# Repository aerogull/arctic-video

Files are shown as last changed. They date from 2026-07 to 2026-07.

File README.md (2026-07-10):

# Arctic-Video
#### An FPGA card designed around video, audio, and PCIe.
Built on a Xilinx Artix-7 75T FPGA chip, with jtag programming, video and audio ports on the card, and DDR3L RAM.

- XC7A75T-2FGG676C
- 256Mb spi flash
- 1GB DDR3L RAM
- 2 6G-SDI ports
- 1 2-lane DisplayPort
- PCIe gen 2 x4 interface
- JTAG programming
- 6 status LEDs

This hardware is untested, use the designs at your own risk!

schematic
pcb
3d model
render

An interactive bom, which includes jlc estimated prices, can be found in the ibom.html file in root. There is a full blend file and a file for the pcb bracket in the cad folder.

JLCPCB estimates:

PCB production costs $165.41

PCBA costs $392.47

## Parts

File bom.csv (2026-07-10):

Designator | Footprint | Quantity | Value | LCSC Part #
C1 | 0402 | 1 | 100u
C10, C11, C13, C16, C20, C23, C26, C28, C29, C47, C48, C49, C50, C51, C52, C53, C54, C55, C56, C57, C58, C59, C60, C61, C62, C63, C64, C65, C66, C76, C77, C78, C79, C8, C80, C81, C82, C83, C84, C85, C86, C87 | 0402 | 42 | 0.47u
C100, C101, C102, C103, C108, C126, C127, C128, C129, C132, C133, C158, C88, C89, C90, C91, C93, C95, C96, C98, C99 | 0402 | 21 | 0.1u
C104, C123, C124, C125, C138, C139, C14, C15, C37, C38, C39, C40, C41, C42, C43, C44, C45, C46, C7, C70, C71, C72, C73, C74, C75, C9, C92, C94, C97 | 0402 | 29 | 4.7u
C105, C107, C109, C110, C111, C122, C142, C143, C144, C145, C150, C152, C3, C4, C5, C6, L1, L2, L3 | 0402 | 19 | 10u
C106 | 0402 | 1 | 1000p
C112 | 0402 | 1 | 2.2u
C113, C114, C115, C116, C117, C118, C119, C120, C134, C135, C146, C147, C148, C149, C151, C153, C154, C155, C156, C157 | 0402 | 20 | 100n
C12, C19, C27, C32, C33, C34, C35, C36, C67, C68, C69 | 0603 | 11 | 47u
C121, C130, C24, C25, C30, C31 | 0402 | 6 | 22u
C131, C136, C137 | 0402 | 3 | 1u
C140, C141 | 0402 | 2 | 470n
C17, C18 | 0402 | 2 | 10n
C2 | 0402 | 1 | 47u
C21, C22 | 0402 | 2 | 3.9n
D1, D2, D3, D4, D5, D6, D7 | 0402 | 7 | LED
IC1, IC2 | QFN40P400X600X100-41N-D | 2 | GS12142
J1 | CONN_47272-0024_MOL | 1 | 472720024
J2, J3 | SAMTEC_BNC7T-J-P-XX-ST-EM1D | 2 | Conn_Coaxial
J4 | PinSocket_2x05_P2.54mm_Vertical | 1 | Conn_ARM_JTAG_SWD_10
J5 | BUS_PCIexpress_x4 | 1 | Bus_PCI_Express_x4
R1, R13, R17, R2, R42, R44, R49, R50, R51, R52, R55, R56, R57, R58, R59, R60 | 0402 | 16 | 100k
R10 | 0402 | 1 | 800
R11, R14, R15, R16, R18, R20, R23, R24, R25, R26, R35, R36, R37, R38, R39, R40, R41, R45, R46, R61, R62, R64, R66, R68, R69, R7, R70, R71, R8 | 0402 | 29 | 10k
R12, R19, R22 | 0402 | 3 | 1M
R21 | 0402 | 1 | 5M
R27, R28, R29, R30, R31, R32, R33, R47 | 0402 | 8 | 1k
R3 | 0402 | 1 | 180
R34 | 0402 | 1 | 240
R4 | 0402 | 1 | 2.2k
R43 | 0402 | 1 | 24.9k
R48 | 0402 | 1 | 22
R5, R6 | 0402 | 2 | 6.8k
R53, R54 | 0402 | 2 | 2
R63 | 0402 | 1 | 100
R65, R67 | 0402 | 2 | 12.1k
R9 | 0402 | 1 | 26.1k
SW1 | SW_DIP_SPSTx08_Slide_9.78x22.5mm_W7.62mm_P2.54mm | 1 | SW_DIP_x08
U1 | Xilinx_FGG676 | 1 | XC7A75T-FGG676
U10 | DRC0010J | 1 | TPS51200DRCR
U11 | DQC0010A | 1 | TPS62175DQCR
U12, U6 | SOT23_NEX | 2 | PESD5V0L2BT
U13, U4 | SOT_AMS1117-2.5_AMS | 2 | AMS1117-ADJ
U2, U3 | IC8_MP2307_MNP | 2 | MP2307DN-LF-Z
U5 | SOT223_AMS1117-1.8_AMS | 1 | AMS1117-1.8
U7 | RTQ0056B | 1 | HD3SS215IRTQT
U8 | SON_EW7-0SIT_MRN | 1 | MT25QL256ABA1EW7-0SIT
U9 | FBGA96_8X14_MRN | 1 | MT41K256M16TW-107:P
XTAL1 | CHIP_ASE-24_ABR | 1 | ASE-25.000MHZ-LC-T
XTAL2 | SG-210STF_EPS | 1 | SX3M100.000B20F30TNN

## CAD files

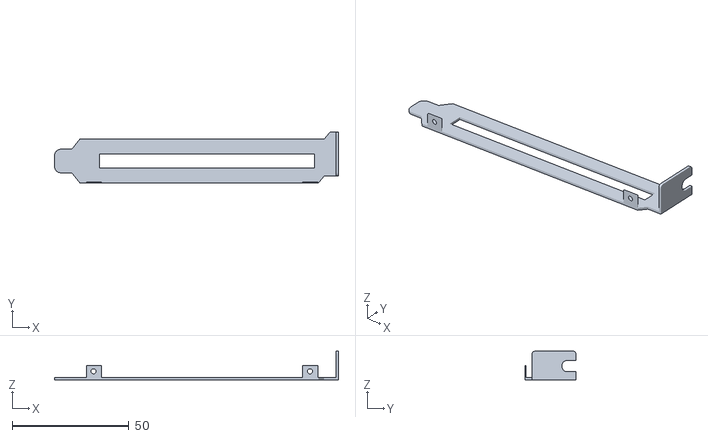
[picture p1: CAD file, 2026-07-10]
cad/arctic-video-bracket.stl
121.4 x 21.8 x 12.3

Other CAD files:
cad/arctic-video.blend

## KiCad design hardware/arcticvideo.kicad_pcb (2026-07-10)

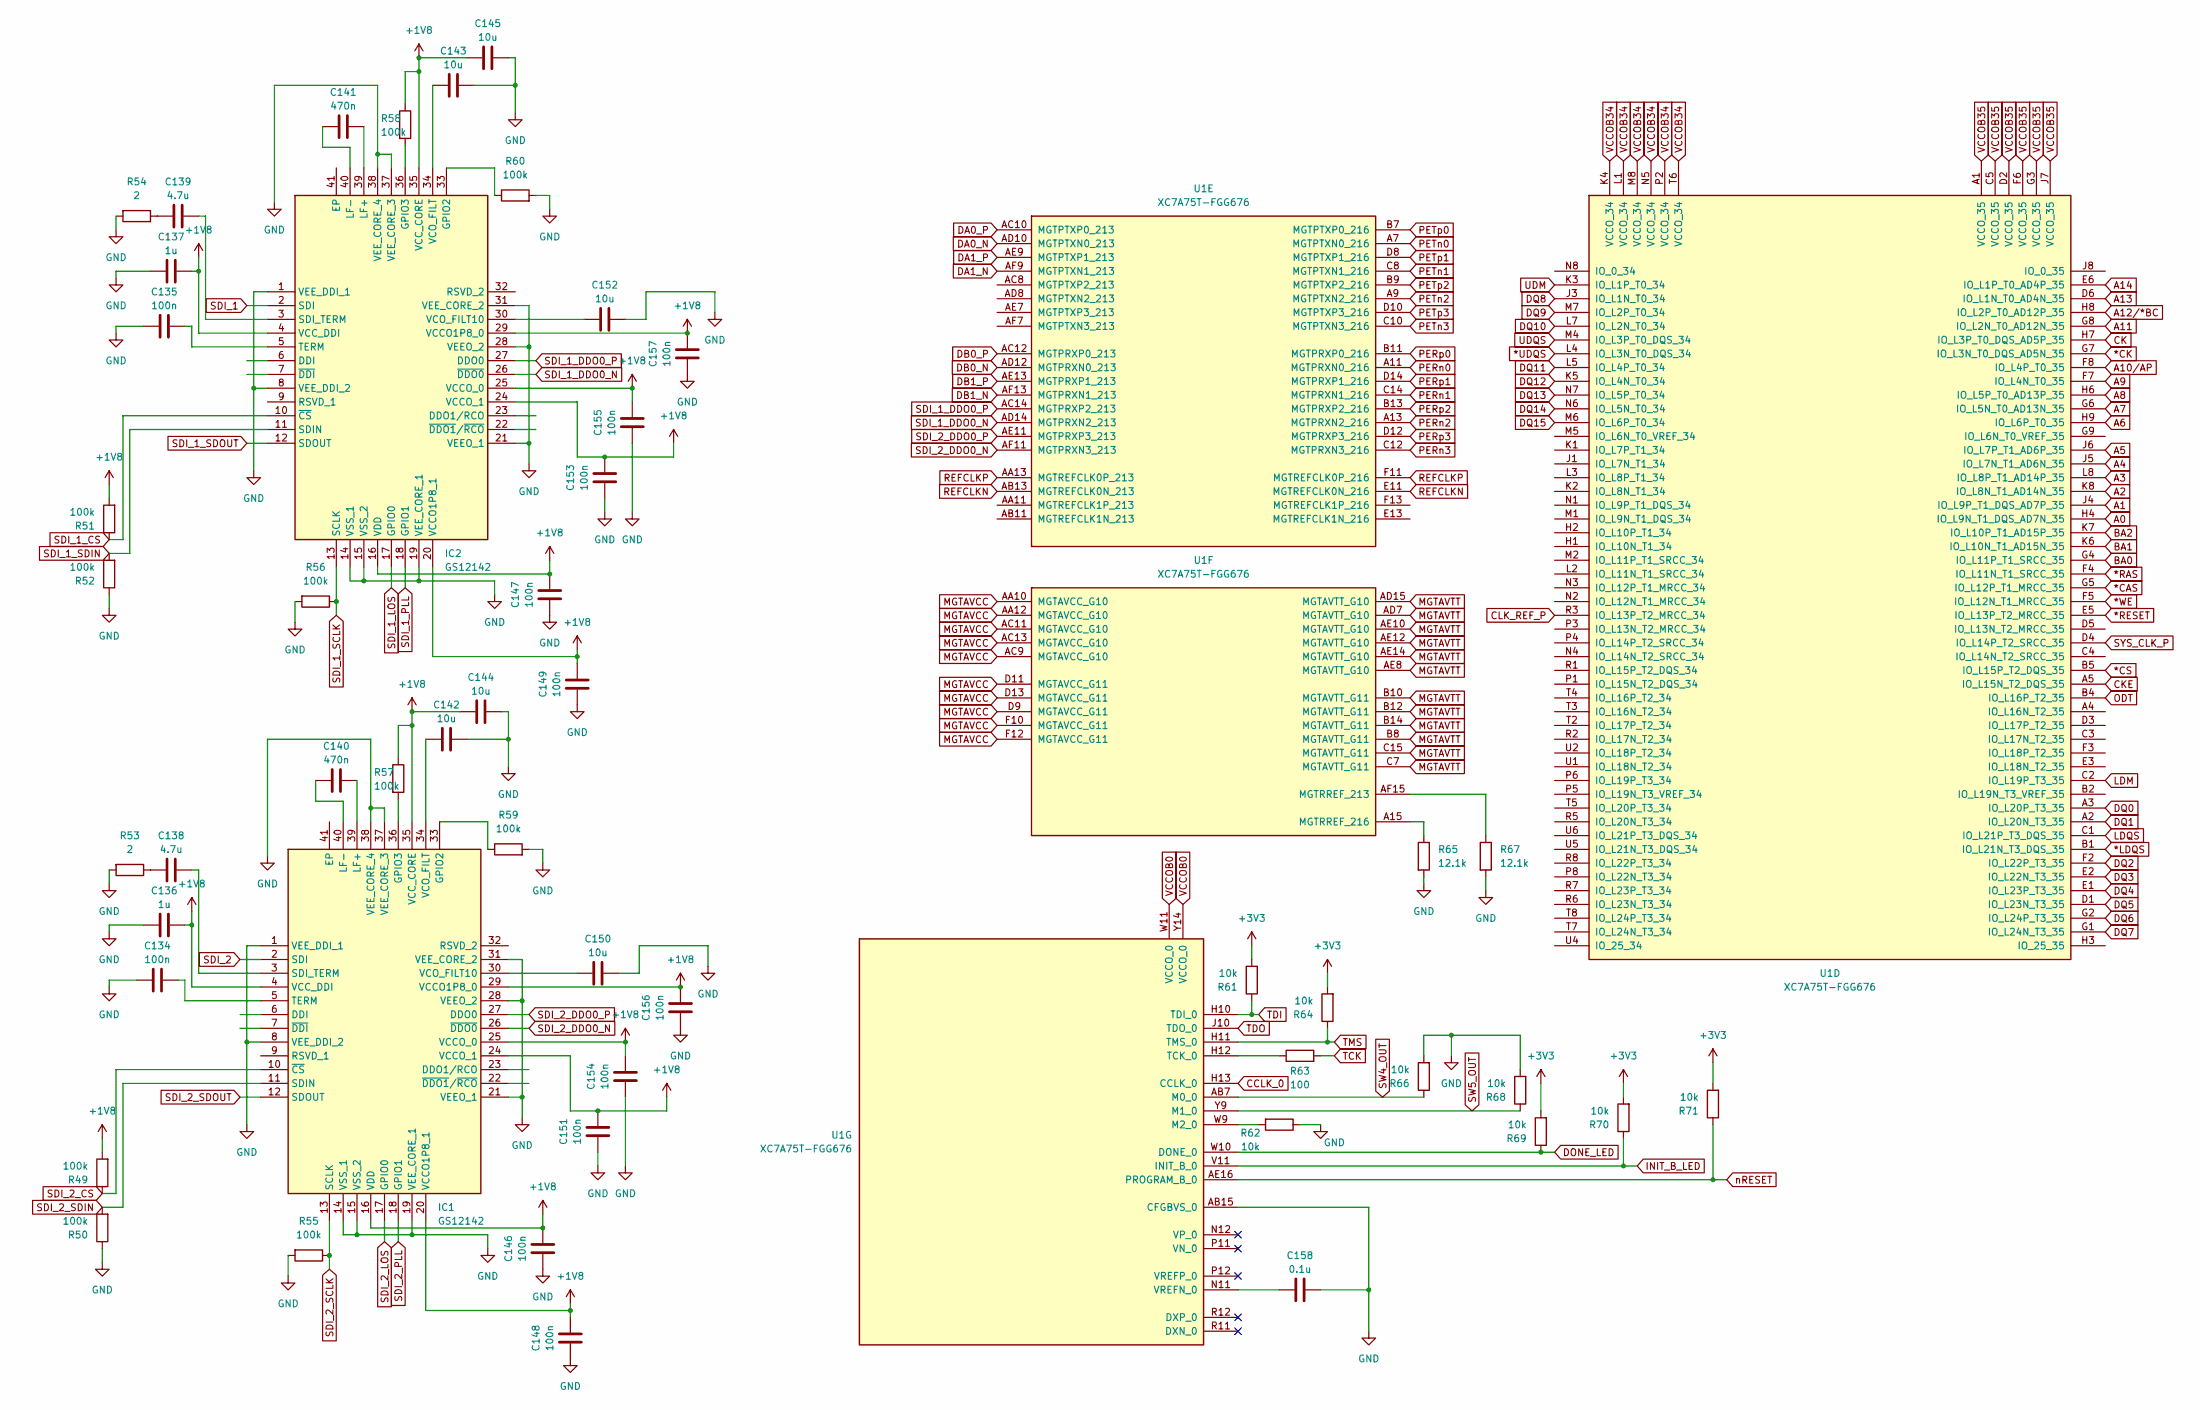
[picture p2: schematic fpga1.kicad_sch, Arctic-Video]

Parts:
C134, C135, C146, C147, C148, C149, C151, C153, C154, C155, C156, C157: 100n; C_0402_1005Metric
C136, C137: 1u; C_0402_1005Metric
C138, C139: 4.7u; C_0402_1005Metric
C140, C141: 470n; C_0402_1005Metric
C142, C143, C144, C145, C150, C152: 10u; C_0402_1005Metric
C158: 0.1u; C_0402_1005Metric
IC1, IC2: GS12142; QFN40P400X600X100-41N-D; Manufacturer_Part_Number GS12142
R49, R50, R51, R52, R55, R56, R57, R58, R59, R60: 100k; R_0402_1005Metric
R53, R54: 2; R_0402_1005Metric
R61, R62, R64, R66, R68, R69, R70, R71: 10k; R_0402_1005Metric
R63: 100; R_0402_1005Metric
R65, R67: 12.1k; R_0402_1005Metric
U1: XC7A75T-FGG676; Xilinx_FGG676

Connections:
*CAS: U1.G5 (IO_L12P_T1_MRCC_35); also elsewhere on the board
*CK: U1.G7 (IO_L3N_T0_DQS_AD5N_35); also elsewhere on the board
*CS: U1.B5 (IO_L15P_T2_DQS_35); also elsewhere on the board
*LDQS: U1.B1 (IO_L21N_T3_DQS_35); also elsewhere on the board
*RAS: U1.F4 (IO_L11N_T1_SRCC_35); also elsewhere on the board
*RESET: U1.E5 (IO_L13P_T2_MRCC_35); also elsewhere on the board
*UDQS: U1.L4 (IO_L3N_T0_DQS_34); also elsewhere on the board
*WE: U1.F5 (IO_L12N_T1_MRCC_35); also elsewhere on the board
A0: U1.H4 (IO_L9N_T1_DQS_AD7N_35); also elsewhere on the board
A1: U1.J4 (IO_L9P_T1_DQS_AD7P_35); also elsewhere on the board
A2: U1.K8 (IO_L8N_T1_AD14N_35); also elsewhere on the board
A3: U1.L8 (IO_L8P_T1_AD14P_35); also elsewhere on the board
A4: U1.J5 (IO_L7N_T1_AD6N_35); also elsewhere on the board
A5: U1.J6 (IO_L7P_T1_AD6P_35); also elsewhere on the board
A6: U1.H9 (IO_L6P_T0_35); also elsewhere on the board
A7: U1.G6 (IO_L5N_T0_AD13N_35); also elsewhere on the board
A8: U1.H6 (IO_L5P_T0_AD13P_35); also elsewhere on the board
A9: U1.F7 (IO_L4N_T0_35); also elsewhere on the board
A10/AP: U1.F8 (IO_L4P_T0_35); also elsewhere on the board
A11: U1.G8 (IO_L2N_T0_AD12N_35); also elsewhere on the board
A12/*BC: U1.H8 (IO_L2P_T0_AD12P_35); also elsewhere on the board
A13: U1.D6 (IO_L1N_T0_AD4N_35); also elsewhere on the board
A14: U1.E6 (IO_L1P_T0_AD4P_35); also elsewhere on the board
BA0: U1.G4 (IO_L11P_T1_SRCC_35); also elsewhere on the board
BA1: U1.K6 (IO_L10N_T1_AD15N_35); also elsewhere on the board
BA2: U1.K7 (IO_L10P_T1_AD15P_35); also elsewhere on the board
CCLK_0: U1.H13 (CCLK_0); also elsewhere on the board
CK: U1.H7 (IO_L3P_T0_DQS_AD5P_35); also elsewhere on the board
CKE: U1.A5 (IO_L15N_T2_DQS_35); also elsewhere on the board
CLK_REF_P: U1.D4 (IO_L14P_T2_SRCC_35), U1.R3 (IO_L13P_T2_MRCC_34); also elsewhere on the board
DA0_N: U1.AD10 (MGTPTXN0_213); also elsewhere on the board
DA0_P: U1.AC10 (MGTPTXP0_213); also elsewhere on the board
DA1_N: U1.AF9 (MGTPTXN1_213); also elsewhere on the board
DA1_P: U1.AE9 (MGTPTXP1_213); also elsewhere on the board
DB0_N: U1.AD12 (MGTPRXN0_213); also elsewhere on the board
DB0_P: U1.AC12 (MGTPRXP0_213); also elsewhere on the board
DB1_N: U1.AF13 (MGTPRXN1_213); also elsewhere on the board
DB1_P: U1.AE13 (MGTPRXP1_213); also elsewhere on the board
DONE_LED: R69.1, U1.W10 (DONE_0); also elsewhere on the board
DQ0: U1.A3 (IO_L20P_T3_35); also elsewhere on the board
DQ1: U1.A2 (IO_L20N_T3_35); also elsewhere on the board
DQ2: U1.F2 (IO_L22P_T3_35); also elsewhere on the board
DQ3: U1.E2 (IO_L22N_T3_35); also elsewhere on the board
DQ4: U1.E1 (IO_L23P_T3_35); also elsewhere on the board
DQ5: U1.D1 (IO_L23N_T3_35); also elsewhere on the board
DQ6: U1.G2 (IO_L24P_T3_35); also elsewhere on the board
DQ7: U1.G1 (IO_L24N_T3_35); also elsewhere on the board
DQ8: U1.J3 (IO_L1N_T0_34); also elsewhere on the board
DQ9: U1.M7 (IO_L2P_T0_34); also elsewhere on the board
DQ10: U1.L7 (IO_L2N_T0_34); also elsewhere on the board
DQ11: U1.L5 (IO_L4P_T0_34); also elsewhere on the board
DQ12: U1.K5 (IO_L4N_T0_34); also elsewhere on the board
DQ13: U1.N7 (IO_L5P_T0_34); also elsewhere on the board
DQ14: U1.N6 (IO_L5N_T0_34); also elsewhere on the board
DQ15: U1.M6 (IO_L6P_T0_34); also elsewhere on the board
GND: C134.1, C135.1, C136.1, C137.1, C142.2, C143.2, C144.2, C145.2, C146.1, C147.1, C148.1, C149.1, C150.2, C151.1, C152.2, C153.1, C154.1, C155.1, C156.1, C157.1, C158.2, IC1.1 (VEE_DDI_1), IC1.8 (VEE_DDI_2), IC1.14 (VSS_1), IC1.15 (VSS_2), IC1.19 (VEE_CORE_1), IC1.21 (VEEO_1), IC1.28 (VEEO_2), IC1.31 (VEE_CORE_2), IC1.37 (VEE_CORE_3), IC1.38 (VEE_CORE_4), IC2.1 (VEE_DDI_1), IC2.8 (VEE_DDI_2), IC2.14 (VSS_1), IC2.15 (VSS_2), IC2.19 (VEE_CORE_1), IC2.21 (VEEO_1), IC2.28 (VEEO_2), IC2.31 (VEE_CORE_2), IC2.37 (VEE_CORE_3), IC2.38 (VEE_CORE_4), R50.1, R52.1, R53.2, R54.2, R55.2, R56.2, R59.2, R60.2, R62.1, R65.2, R66.2, R67.2, R68.2, U1.AB15 (CFGBVS_0); also elsewhere on the board
INIT_B_LED: R70.1, U1.V11 (INIT_B_0); also elsewhere on the board
LDM: U1.C2 (IO_L19P_T3_35); also elsewhere on the board
LDQS: U1.C1 (IO_L21P_T3_DQS_35); also elsewhere on the board
MGTAVCC: U1.AA10 (MGTAVCC_G10), U1.AA12 (MGTAVCC_G10), U1.AC9 (MGTAVCC_G10), U1.AC11 (MGTAVCC_G10), U1.AC13 (MGTAVCC_G10), U1.D9 (MGTAVCC_G11), U1.D11 (MGTAVCC_G11), U1.D13 (MGTAVCC_G11), U1.F10 (MGTAVCC_G11), U1.F12 (MGTAVCC_G11); also elsewhere on the board
MGTAVTT: U1.AD7 (MGTAVTT_G10), U1.AD15 (MGTAVTT_G10), U1.AE8 (MGTAVTT_G10), U1.AE10 (MGTAVTT_G10), U1.AE12 (MGTAVTT_G10), U1.AE14 (MGTAVTT_G10), U1.B8 (MGTAVTT_G11), U1.B10 (MGTAVTT_G11), U1.B12 (MGTAVTT_G11), U1.B14 (MGTAVTT_G11), U1.C7 (MGTAVTT_G11), U1.C15 (MGTAVTT_G11); also elsewhere on the board
unnamed: C138.1, R53.1
unnamed: C139.1, R54.1
unnamed: IC1.33 (GPIO2), R59.1
unnamed: IC1.36 (GPIO3), R57.2
unnamed: C140.2, IC1.39 (LF+)
unnamed: C140.1, IC1.40 (LF-)
unnamed: C138.2, IC1.3 (SDI_TERM)
unnamed: C134.2, IC1.5 (TERM)
unnamed: C150.1, IC1.30 (VCO_FILT10)
unnamed: C142.1, IC1.34 (VCO_FILT)
unnamed: IC2.33 (GPIO2), R60.1
unnamed: IC2.36 (GPIO3), R58.2
unnamed: C141.2, IC2.39 (LF+)
unnamed: C141.1, IC2.40 (LF-)
unnamed: C139.2, IC2.3 (SDI_TERM)
unnamed: C135.2, IC2.5 (TERM)
unnamed: C152.1, IC2.30 (VCO_FILT10)
unnamed: C143.1, IC2.34 (VCO_FILT)
unnamed: R67.1, U1.AF15 (MGTRREF_213)
unnamed: R65.1, U1.A15 (MGTRREF_216)
unnamed: R62.2, U1.W9 (M2_0)
unnamed: R63.1, U1.H12 (TCK_0)
unnamed: C158.1, U1.N11 (VREFN_0)
ODT: U1.B4 (IO_L16P_T2_35); also elsewhere on the board
PERn0: U1.A11 (MGTPRXN0_216); also elsewhere on the board
PERn1: U1.C14 (MGTPRXN1_216); also elsewhere on the board
PERn2: U1.A13 (MGTPRXN2_216); also elsewhere on the board
PERn3: U1.C12 (MGTPRXN3_216); also elsewhere on the board
PERp0: U1.B11 (MGTPRXP0_216); also elsewhere on the board
PERp1: U1.D14 (MGTPRXP1_216); also elsewhere on the board
PERp2: U1.B13 (MGTPRXP2_216); also elsewhere on the board
PERp3: U1.D12 (MGTPRXP3_216); also elsewhere on the board
PETn0: U1.A7 (MGTPTXN0_216); also elsewhere on the board
PETn1: U1.C8 (MGTPTXN1_216); also elsewhere on the board
PETn2: U1.A9 (MGTPTXN2_216); also elsewhere on the board
PETn3: U1.C10 (MGTPTXN3_216); also elsewhere on the board
PETp0: U1.B7 (MGTPTXP0_216); also elsewhere on the board
PETp1: U1.D8 (MGTPTXP1_216); also elsewhere on the board
PETp2: U1.B9 (MGTPTXP2_216); also elsewhere on the board
PETp3: U1.D10 (MGTPTXP3_216); also elsewhere on the board
REFCLKN: U1.AB13 (MGTREFCLK0N_213), U1.E11 (MGTREFCLK0N_216); also elsewhere on the board
REFCLKP: U1.AA13 (MGTREFCLK0P_213), U1.F11 (MGTREFCLK0P_216); also elsewhere on the board
SDI_1: IC2.2 (SDI); also elsewhere on the board
SDI_1_CS: IC2.10 (~CS), R51.1; also elsewhere on the board
SDI_1_DDO0_N: IC2.26 (~DDO0), U1.AD14 (MGTPRXN2_213)
SDI_1_DDO0_P: IC2.27 (DDO0), U1.AC14 (MGTPRXP2_213)
SDI_1_LOS: IC2.17 (GPIO0); also elsewhere on the board
SDI_1_PLL: IC2.18 (GPIO1); also elsewhere on the board
SDI_1_SCLK: IC2.13 (SCLK), R56.1; also elsewhere on the board
SDI_1_SDIN: IC2.11 (SDIN), R52.2; also elsewhere on the board
SDI_1_SDOUT: IC2.12 (SDOUT); also elsewhere on the board
SDI_2: IC1.2 (SDI); also elsewhere on the board
SDI_2_CS: IC1.10 (~CS), R49.1; also elsewhere on the board
SDI_2_DDO0_N: IC1.26 (~DDO0), U1.AF11 (MGTPRXN3_213)
SDI_2_DDO0_P: IC1.27 (DDO0), U1.AE11 (MGTPRXP3_213)
SDI_2_LOS: IC1.17 (GPIO0); also elsewhere on the board
SDI_2_PLL: IC1.18 (GPIO1); also elsewhere on the board
SDI_2_SCLK: IC1.13 (SCLK), R55.1; also elsewhere on the board
SDI_2_SDIN: IC1.11 (SDIN), R50.2; also elsewhere on the board
SDI_2_SDOUT: IC1.12 (SDOUT); also elsewhere on the board
SW4_OUT: R66.1, U1.AB7 (M0_0); also elsewhere on the board
SW5_OUT: R68.1, U1.Y9 (M1_0); also elsewhere on the board
TCK: R63.2; also elsewhere on the board
TDI: R61.1, U1.H10 (TDI_0); also elsewhere on the board
TDO: U1.J10 (TDO_0); also elsewhere on the board
TMS: R64.1, U1.H11 (TMS_0); also elsewhere on the board
UDM: U1.K3 (IO_L1P_T0_34); also elsewhere on the board
UDQS: U1.M4 (IO_L3P_T0_DQS_34); also elsewhere on the board
VCCAUX: C136.2, C137.2, C144.1, C145.1, C146.2, C147.2, C148.2, C149.2, C151.2, C153.2, C154.2, C155.2, C156.2, C157.2, IC1.4 (VCC_DDI), IC1.16 (VDD), IC1.20 (VCCO1P8_1), IC1.24 (VCCO_1), IC1.25 (VCCO_0), IC1.29 (VCCO1P8_0), IC1.35 (VCC_CORE), IC2.4 (VCC_DDI), IC2.16 (VDD), IC2.20 (VCCO1P8_1), IC2.24 (VCCO_1), IC2.25 (VCCO_0), IC2.29 (VCCO1P8_0), IC2.35 (VCC_CORE), R49.2, R51.2, R57.1, R58.1; also elsewhere on the board
VCCOB0: R61.2, R64.2, R69.2, R70.2, R71.2, U1.W11 (VCCO_0), U1.Y14 (VCCO_0); also elsewhere on the board
VCCOB33: U1.A1 (VCCO_35), U1.C5 (VCCO_35), U1.D2 (VCCO_35), U1.F6 (VCCO_35), U1.G3 (VCCO_35), U1.J7 (VCCO_35), U1.K4 (VCCO_34), U1.L1 (VCCO_34), U1.M8 (VCCO_34), U1.N5 (VCCO_34), U1.P2 (VCCO_34), U1.T6 (VCCO_34); also elsewhere on the board
nRESET: R71.1, U1.AE16 (PROGRAM_B_0); also elsewhere on the board

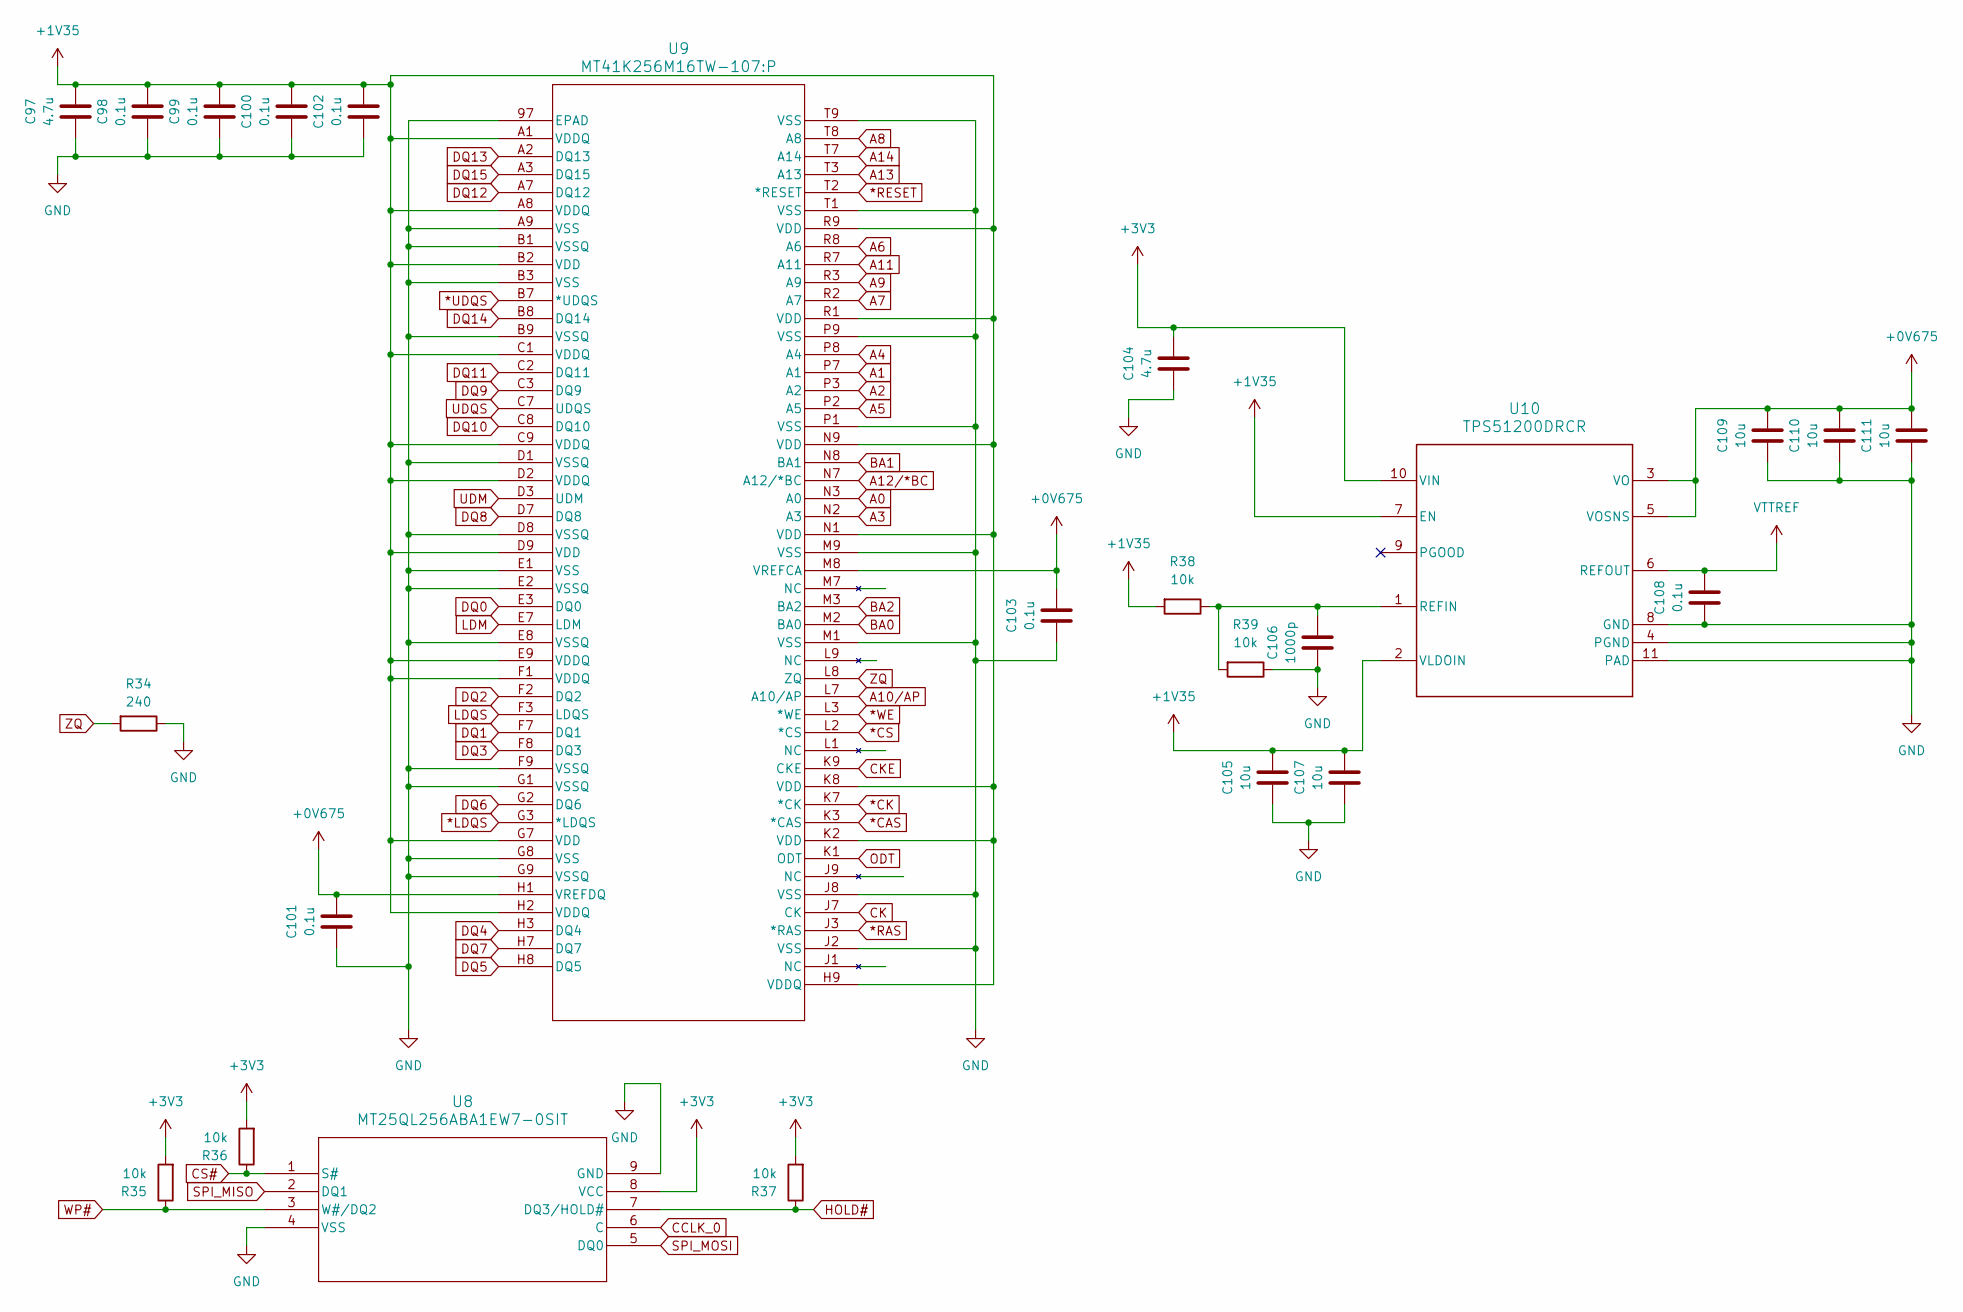
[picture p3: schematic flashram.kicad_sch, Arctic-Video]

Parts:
C97, C104: 4.7u; C_0402_1005Metric
C98, C99, C100, C101, C102, C103, C108: 0.1u; C_0402_1005Metric
C105, C107, C109, C110, C111: 10u; C_0402_1005Metric
C106: 1000p; C_0402_1005Metric
R34: 240; R_0402_1005Metric
R35, R36, R37, R38, R39: 10k; R_0402_1005Metric
U8: MT25QL256ABA1EW7-0SIT; SON_EW7-0SIT_MRN
U9: MT41K256M16TW-107:P; FBGA96_8X14_MRN
U10: TPS51200DRCR; DRC0010J

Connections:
*CAS: U9.K3 (*CAS); also elsewhere on the board
*CK: U9.K7 (*CK); also elsewhere on the board
*CS: U9.L2 (*CS); also elsewhere on the board
*LDQS: U9.G3 (*LDQS); also elsewhere on the board
*RAS: U9.J3 (*RAS); also elsewhere on the board
*RESET: U9.T2 (*RESET); also elsewhere on the board
*UDQS: U9.B7 (*UDQS); also elsewhere on the board
*WE: U9.L3 (*WE); also elsewhere on the board
+0V675: C101.2, C103.2, C109.2, C110.2, C111.2, U9.H1 (VREFDQ), U9.M8 (VREFCA), U10.3 (VO), U10.5 (VOSNS)
A0: U9.N3 (A0); also elsewhere on the board
A1: U9.P7 (A1); also elsewhere on the board
A2: U9.P3 (A2); also elsewhere on the board
A3: U9.N2 (A3); also elsewhere on the board
A4: U9.P8 (A4); also elsewhere on the board
A5: U9.P2 (A5); also elsewhere on the board
A6: U9.R8 (A6); also elsewhere on the board
A7: U9.R2 (A7); also elsewhere on the board
A8: U9.T8 (A8); also elsewhere on the board
A9: U9.R3 (A9); also elsewhere on the board
A10/AP: U9.L7 (A10/AP); also elsewhere on the board
A11: U9.R7 (A11); also elsewhere on the board
A12/*BC: U9.N7 (A12/*BC); also elsewhere on the board
A13: U9.T3 (A13); also elsewhere on the board
A14: U9.T7 (A14); also elsewhere on the board
BA0: U9.M2 (BA0); also elsewhere on the board
BA1: U9.N8 (BA1); also elsewhere on the board
BA2: U9.M3 (BA2); also elsewhere on the board
CCLK_0: U8.6 (C); also elsewhere on the board
CK: U9.J7 (CK); also elsewhere on the board
CKE: U9.K9 (CKE); also elsewhere on the board
CS#: R36.1, U8.1 (S#); also elsewhere on the board
DQ0: U9.E3 (DQ0); also elsewhere on the board
DQ1: U9.F7 (DQ1); also elsewhere on the board
DQ2: U9.F2 (DQ2); also elsewhere on the board
DQ3: U9.F8 (DQ3); also elsewhere on the board
DQ4: U9.H3 (DQ4); also elsewhere on the board
DQ5: U9.H8 (DQ5); also elsewhere on the board
DQ6: U9.G2 (DQ6); also elsewhere on the board
DQ7: U9.H7 (DQ7); also elsewhere on the board
DQ8: U9.D7 (DQ8); also elsewhere on the board
DQ9: U9.C3 (DQ9); also elsewhere on the board
DQ10: U9.C8 (DQ10); also elsewhere on the board
DQ11: U9.C2 (DQ11); also elsewhere on the board
DQ12: U9.A7 (DQ12); also elsewhere on the board
DQ13: U9.A2 (DQ13); also elsewhere on the board
DQ14: U9.B8 (DQ14); also elsewhere on the board
DQ15: U9.A3 (DQ15); also elsewhere on the board
GND: C97.1, C98.1, C99.1, C100.1, C101.1, C102.1, C103.1, C104.1, C105.1, C106.1, C107.1, C108.1, C109.1, C110.1, C111.1, R34.1, R39.1, U8.4 (VSS), U8.9 (GND), U9.97 (EPAD), U9.A9 (VSS), U9.B1 (VSSQ), U9.B3 (VSS), U9.B9 (VSSQ), U9.D1 (VSSQ), U9.D8 (VSSQ), U9.E1 (VSS), U9.E2 (VSSQ), U9.E8 (VSSQ), U9.F9 (VSSQ), U9.G1 (VSSQ), U9.G8 (VSS), U9.G9 (VSSQ), U9.J2 (VSS), U9.J8 (VSS), U9.M1 (VSS), U9.M9 (VSS), U9.P1 (VSS), U9.P9 (VSS), U9.T1 (VSS), U9.T9 (VSS), U10.4 (PGND), U10.8 (GND), U10.11 (PAD); also elsewhere on the board
HOLD#: R37.1, U8.7 (DQ3/HOLD#); also elsewhere on the board
LDM: U9.E7 (LDM); also elsewhere on the board
LDQS: U9.F3 (LDQS); also elsewhere on the board
unnamed: C106.2, R38.1, R39.2, U10.1 (REFIN)
ODT: U9.K1 (ODT); also elsewhere on the board
SPI_MISO: U8.2 (DQ1); also elsewhere on the board
SPI_MOSI: U8.5 (DQ0); also elsewhere on the board
UDM: U9.D3 (UDM); also elsewhere on the board
UDQS: U9.C7 (UDQS); also elsewhere on the board
VCCOB0: C104.2, R35.2, R36.2, R37.2, U8.8 (VCC), U10.10 (VIN); also elsewhere on the board
VCCOB33: C97.2, C98.2, C99.2, C100.2, C102.2, C105.2, C107.2, R38.2, U9.A1 (VDDQ), U9.A8 (VDDQ), U9.B2 (VDD), U9.C1 (VDDQ), U9.C9 (VDDQ), U9.D2 (VDDQ), U9.D9 (VDD), U9.E9 (VDDQ), U9.F1 (VDDQ), U9.G7 (VDD), U9.H2 (VDDQ), U9.H9 (VDDQ), U9.K2 (VDD), U9.K8 (VDD), U9.N1 (VDD), U9.N9 (VDD), U9.R1 (VDD), U9.R9 (VDD), U10.2 (VLDOIN), U10.7 (EN); also elsewhere on the board
VTTREF: C108.2, U10.6 (REFOUT)
WP#: R35.1, U8.3 (W#/DQ2); also elsewhere on the board
ZQ: R34.2, U9.L8 (ZQ)

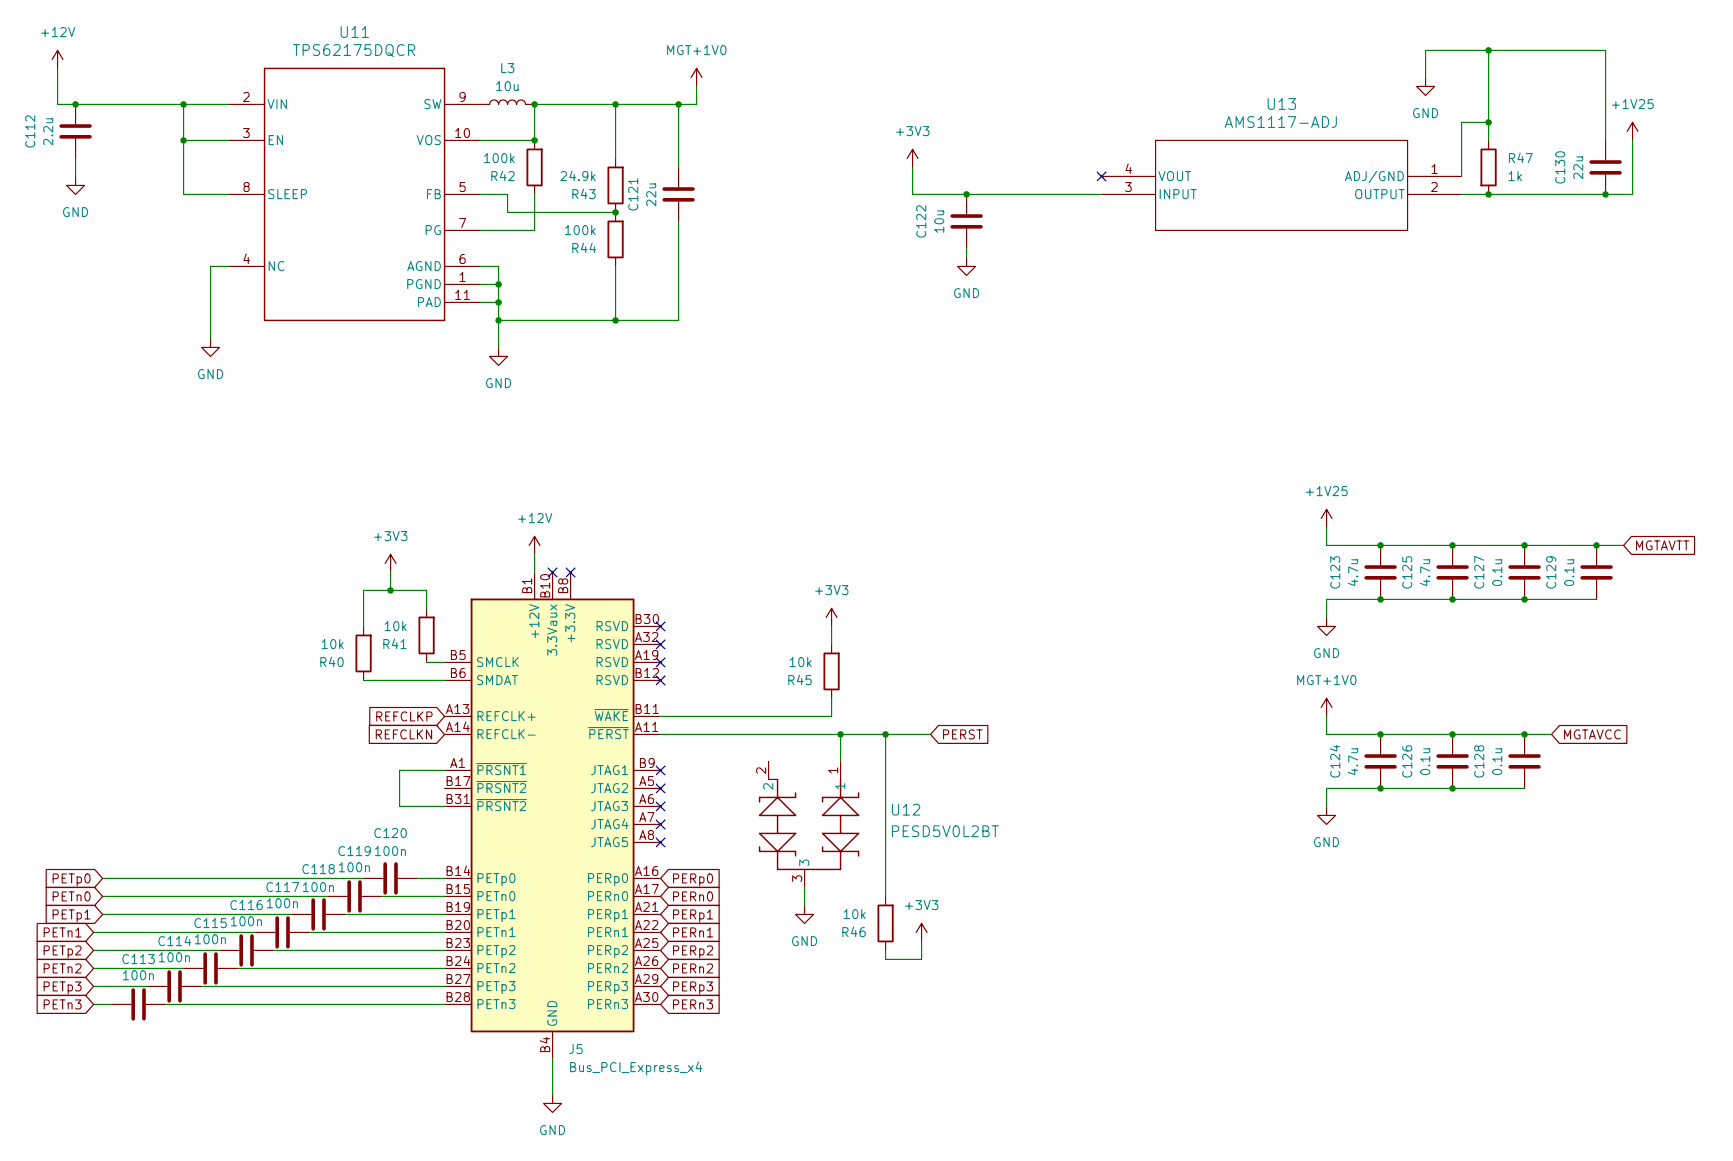
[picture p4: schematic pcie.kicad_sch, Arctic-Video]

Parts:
C112: 2.2u; C_0402_1005Metric
C113, C114, C115, C116, C117, C118, C119, C120: 100n; C_0402_1005Metric
C121, C130: 22u; C_0402_1005Metric
C122: 10u; C_0402_1005Metric
C123, C124, C125: 4.7u; C_0402_1005Metric
C126, C127, C128, C129: 0.1u; C_0402_1005Metric
J5: Bus_PCI_Express_x4; BUS_PCIexpress_x4
L3: 10u; L_0402_1005Metric
R40, R41, R45, R46: 10k; R_0402_1005Metric
R42, R44: 100k; R_0402_1005Metric
R43: 24.9k; R_0402_1005Metric
R47: 1k; R_0402_1005Metric
U11: TPS62175DQCR; DQC0010A
U12: PESD5V0L2BT; SOT23_NEX
U13: AMS1117-ADJ; SOT_AMS1117-2.5_AMS

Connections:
+12V: C112.2, J5.A2 (+12V), J5.A3 (+12V), J5.B1 (+12V), J5.B2 (+12V), J5.B3 (+12V), U11.2 (VIN), U11.3 (EN), U11.8 (SLEEP); also elsewhere on the board
GND: C112.1, C121.1, C122.1, C123.1, C124.1, C125.1, C126.1, C127.1, C128.1, C129.1, C130.2, J5.A4 (GND), J5.A12 (GND), J5.A15 (GND), J5.A18 (GND), J5.A20 (GND), J5.A23 (GND), J5.A24 (GND), J5.A27 (GND), J5.A28 (GND), J5.A31 (GND), J5.B4 (GND), J5.B7 (GND), J5.B13 (GND), J5.B16 (GND), J5.B18 (GND), J5.B21 (GND), J5.B22 (GND), J5.B25 (GND), J5.B26 (GND), J5.B29 (GND), J5.B32 (GND), R44.1, R47.1, U11.1 (PGND), U11.4 (NC), U11.6 (AGND), U11.11 (PAD), U12.3, U13.1 (ADJ/GND); also elsewhere on the board
MGTAVCC: C121.2, C124.2, C126.2, C128.2, L3.2, R42.2, R43.2, U11.10 (VOS); also elsewhere on the board
MGTAVTT: C123.2, C125.2, C127.2, C129.2, C130.1, R47.2, U13.2 (OUTPUT); also elsewhere on the board
unnamed: C119.2, J5.B15 (PETn0)
unnamed: C117.2, J5.B20 (PETn1)
unnamed: C115.2, J5.B24 (PETn2)
unnamed: C113.2, J5.B28 (PETn3)
unnamed: C120.2, J5.B14 (PETp0)
unnamed: C118.2, J5.B19 (PETp1)
unnamed: C116.2, J5.B23 (PETp2)
unnamed: C114.2, J5.B27 (PETp3)
unnamed: J5.B5 (SMCLK), R41.1
unnamed: J5.B6 (SMDAT), R40.1
unnamed: J5.A1 (~PRSNT1), J5.B31 (~PRSNT2)
unnamed: J5.B11 (~WAKE), R45.1
unnamed: R43.1, R44.2, U11.5 (FB)
unnamed: R42.1, U11.7 (PG)
unnamed: L3.1, U11.9 (SW)
PERST: J5.A11 (~PERST), R46.2, U12.1; also elsewhere on the board
PERn0: J5.A17 (PERn0); also elsewhere on the board
PERn1: J5.A22 (PERn1); also elsewhere on the board
PERn2: J5.A26 (PERn2); also elsewhere on the board
PERn3: J5.A30 (PERn3); also elsewhere on the board
PERp0: J5.A16 (PERp0); also elsewhere on the board
PERp1: J5.A21 (PERp1); also elsewhere on the board
PERp2: J5.A25 (PERp2); also elsewhere on the board
PERp3: J5.A29 (PERp3); also elsewhere on the board
PETn0: C119.1; also elsewhere on the board
PETn1: C117.1; also elsewhere on the board
PETn2: C115.1; also elsewhere on the board
PETn3: C113.1; also elsewhere on the board
PETp0: C120.1; also elsewhere on the board
PETp1: C118.1; also elsewhere on the board
PETp2: C116.1; also elsewhere on the board
PETp3: C114.1; also elsewhere on the board
REFCLKN: J5.A14 (REFCLK-); also elsewhere on the board
REFCLKP: J5.A13 (REFCLK+); also elsewhere on the board
VCCOB0: C122.2, R40.2, R41.2, R45.2, R46.1, U13.3 (INPUT); also elsewhere on the board

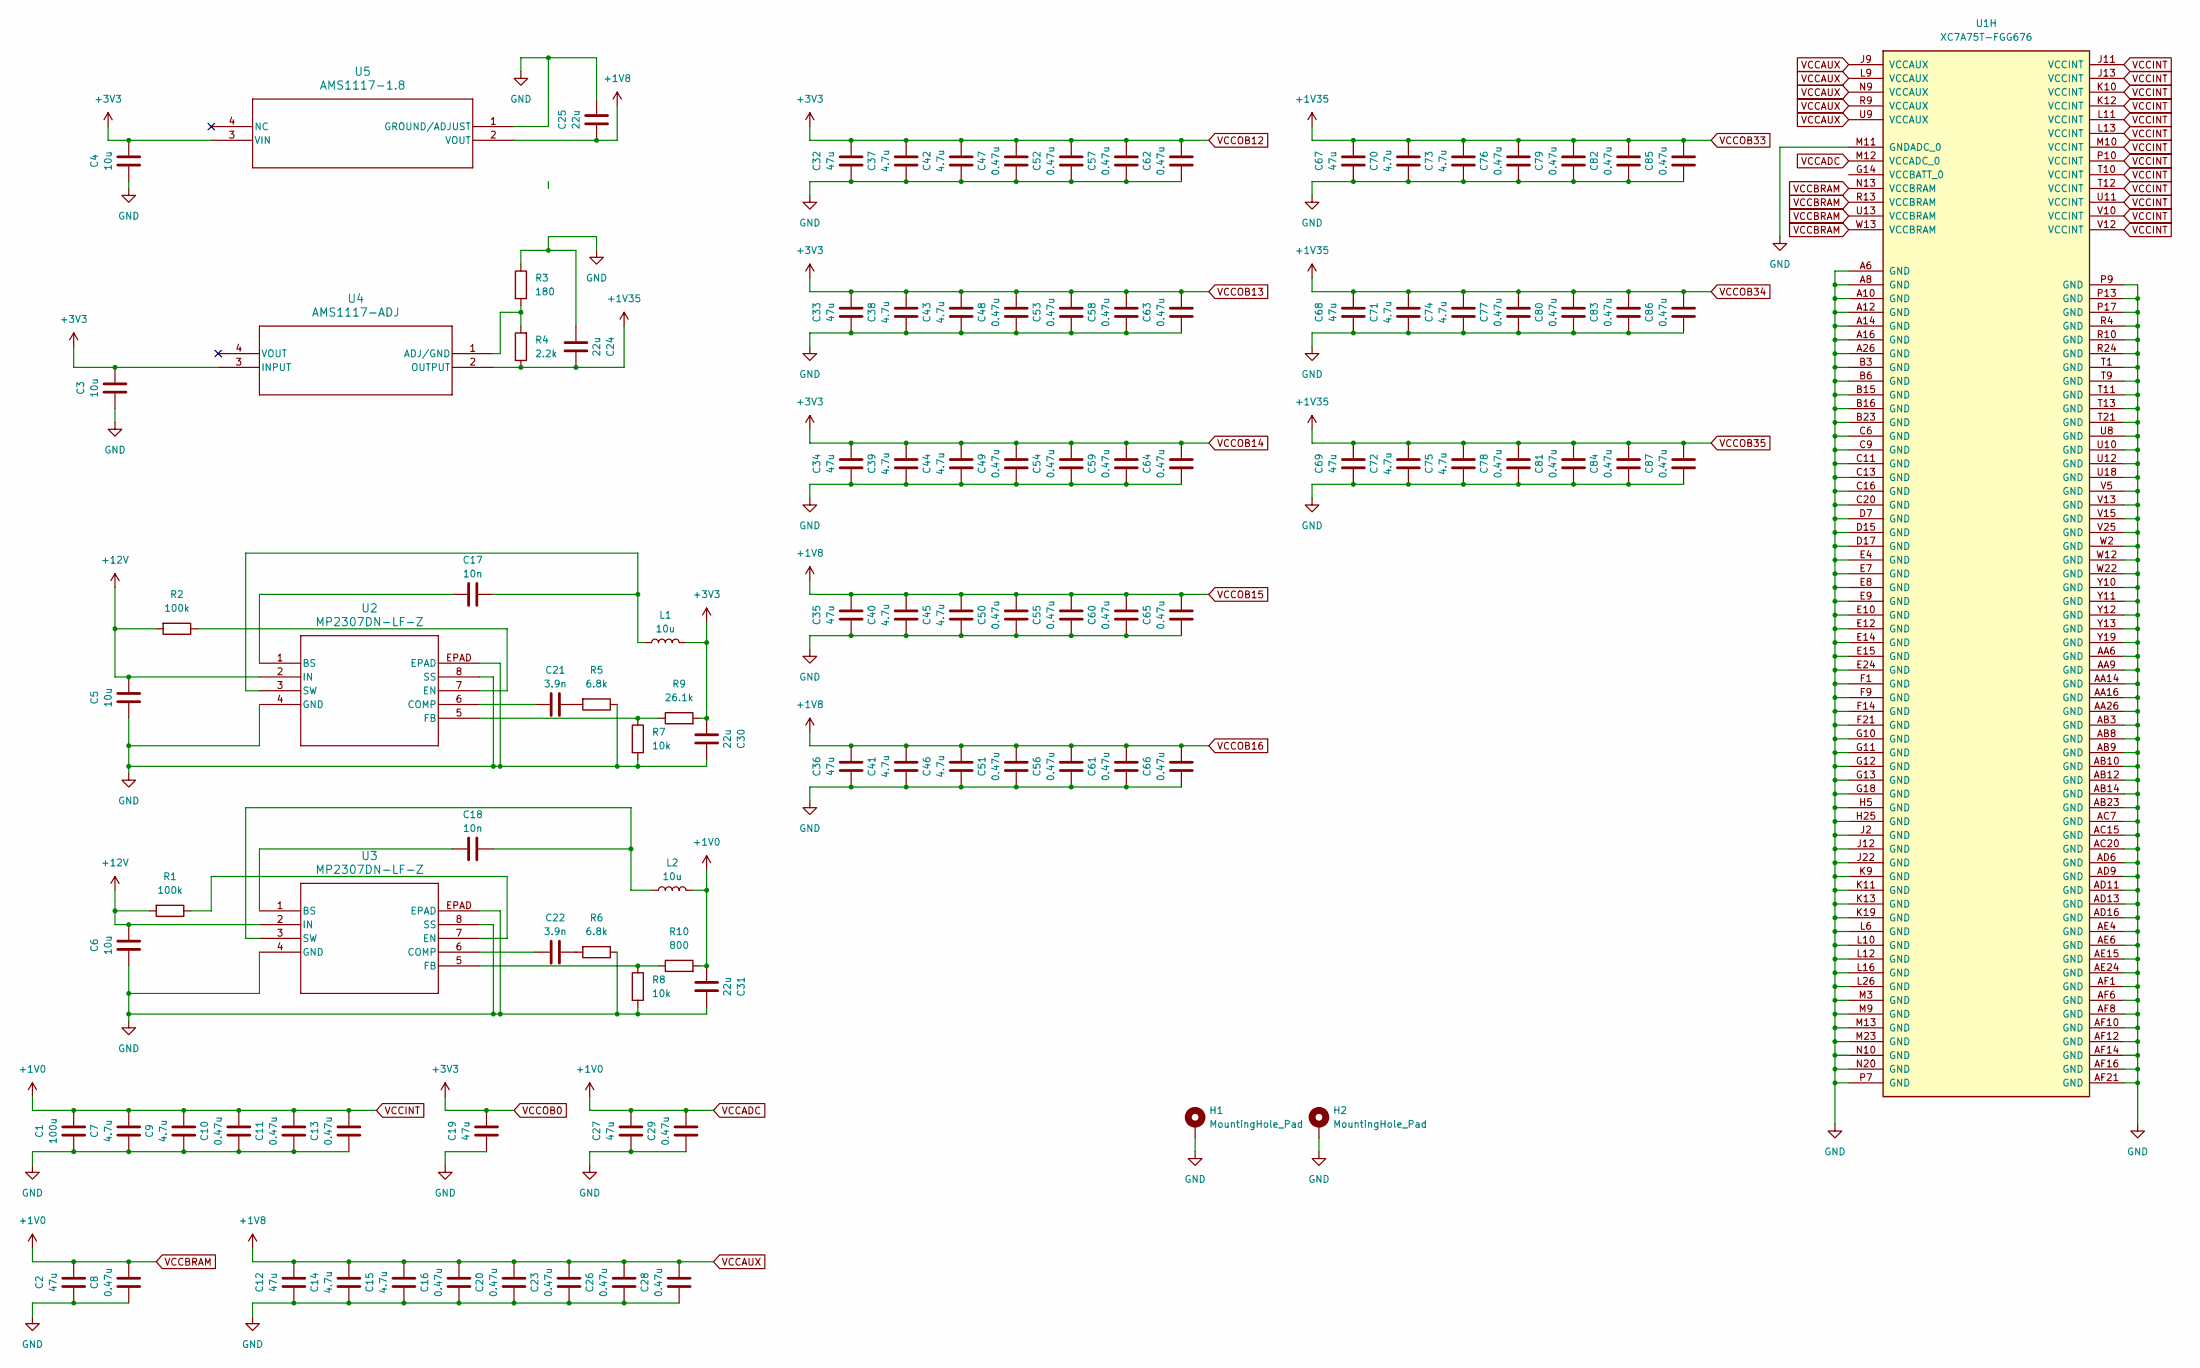
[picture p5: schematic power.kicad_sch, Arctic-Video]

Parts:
C1: 100u; C_0402_1005Metric
C2: 47u; C_0402_1005Metric
C3, C4, C5, C6: 10u; C_0402_1005Metric
C7, C9, C14, C15, C37, C38, C39, C40, C41, C42, C43, C44, C45, C46, C70, C71, C72, C73, C74, C75: 4.7u; C_0402_1005Metric
C8, C10, C11, C13, C16, C20, C23, C26, C28, C29, C47, C48, C49, C50, C51, C52, C53, C54, C55, C56, C57, C58, C59, C60, C61, C62, C63, C64, C65, C66, C76, C77, C78, C79, C80, C81, C82, C83, C84, C85, C86, C87: 0.47u; C_0402_1005Metric
C12, C19, C27, C32, C33, C34, C35, C36, C67, C68, C69: 47u; C_0603_1608Metric
C17, C18: 10n; C_0402_1005Metric
C21, C22: 3.9n; C_0402_1005Metric
C24, C25, C30, C31: 22u; C_0402_1005Metric
H1: MountingHole_Pad; MountingHole_2.7mm_Pad_Via
H2: MountingHole_Pad; MountingHole_3mm_Pad_Via
L1, L2: 10u; L_0402_1005Metric
R1, R2: 100k; R_0402_1005Metric
R3: 180; R_0402_1005Metric
R4: 2.2k; R_0402_1005Metric
R5, R6: 6.8k; R_0402_1005Metric
R7, R8: 10k; R_0402_1005Metric
R9: 26.1k; R_0402_1005Metric
R10: 800; R_0402_1005Metric
U1: XC7A75T-FGG676; Xilinx_FGG676
U2, U3: MP2307DN-LF-Z; IC8_MP2307_MNP
U4: AMS1117-ADJ; SOT_AMS1117-2.5_AMS
U5: AMS1117-1.8; SOT223_AMS1117-1.8_AMS

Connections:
+12V: C5.2, C6.2, R1.2, R2.2, U2.2 (IN), U3.2 (IN); also elsewhere on the board
GND: C1.1, C2.1, C3.1, C4.1, C5.1, C6.1, C7.1, C8.1, C9.1, C10.1, C11.1, C12.1, C13.1, C14.1, C15.1, C16.1, C19.1, C20.1, C23.1, C24.1, C25.2, C26.1, C27.1, C28.1, C29.1, C30.2, C31.2, C32.1, C33.1, C34.1, C35.1, C36.1, C37.1, C38.1, C39.1, C40.1, C41.1, C42.1, C43.1, C44.1, C45.1, C46.1, C47.1, C48.1, C49.1, C50.1, C51.1, C52.1, C53.1, C54.1, C55.1, C56.1, C57.1, C58.1, C59.1, C60.1, C61.1, C62.1, C63.1, C64.1, C65.1, C66.1, C67.1, C68.1, C69.1, C70.1, C71.1, C72.1, C73.1, C74.1, C75.1, C76.1, C77.1, C78.1, C79.1, C80.1, C81.1, C82.1, C83.1, C84.1, C85.1, C86.1, C87.1, H1.1 (1_1), H2.1 (1_1), R3.1, R5.1, R6.1, R7.2, R8.2, U1.A6 (GND), U1.A8 (GND), U1.A10 (GND), U1.A12 (GND), U1.A14 (GND), U1.A16 (GND), U1.A26 (GND), U1.AA6 (GND), U1.AA9 (GND), U1.AA14 (GND), U1.AA16 (GND), U1.AA26 (GND), U1.AB3 (GND), U1.AB8 (GND), U1.AB9 (GND), U1.AB10 (GND), U1.AB12 (GND), U1.AB14 (GND), U1.AB23 (GND), U1.AC7 (GND), U1.AC15 (GND), U1.AC20 (GND), U1.AD6 (GND), U1.AD9 (GND), U1.AD11 (GND), U1.AD13 (GND), U1.AD16 (GND), U1.AE4 (GND), U1.AE6 (GND), U1.AE15 (GND), U1.AE24 (GND), U1.AF1 (GND), U1.AF6 (GND), U1.AF8 (GND), U1.AF10 (GND), U1.AF12 (GND), U1.AF14 (GND), U1.AF16 (GND), U1.AF21 (GND), U1.B3 (GND), U1.B6 (GND), U1.B15 (GND), U1.B16 (GND), U1.B23 (GND), U1.C6 (GND), U1.C9 (GND), U1.C11 (GND), U1.C13 (GND), U1.C16 (GND), U1.C20 (GND), U1.D7 (GND), U1.D15 (GND), U1.D17 (GND), U1.E4 (GND), U1.E7 (GND), U1.E8 (GND), U1.E9 (GND), U1.E10 (GND), U1.E12 (GND), U1.E14 (GND), U1.E15 (GND), U1.E24 (GND), U1.F1 (GND), U1.F9 (GND), U1.F14 (GND), U1.F21 (GND), U1.G10 (GND), U1.G11 (GND), U1.G12 (GND), U1.G13 (GND), U1.G18 (GND), U1.H5 (GND), U1.H25 (GND), U1.J2 (GND), U1.J12 (GND), U1.J22 (GND), U1.K9 (GND), U1.K11 (GND), U1.K13 (GND), U1.K19 (GND), U1.L6 (GND), U1.L10 (GND), U1.L12 (GND), U1.L16 (GND), U1.L26 (GND), U1.M3 (GND), U1.M9 (GND), U1.M11 (GNDADC_0), U1.M13 (GND), U1.M23 (GND), U1.N10 (GND), U1.N20 (GND), U1.P7 (GND), U1.P9 (GND), U1.P13 (GND), U1.P17 (GND), U1.R4 (GND), U1.R10 (GND), U1.R24 (GND), U1.T1 (GND), U1.T9 (GND), U1.T11 (GND), U1.T13 (GND), U1.T21 (GND), U1.U8 (GND), U1.U10 (GND), U1.U12 (GND), U1.U18 (GND), U1.V5 (GND), U1.V13 (GND), U1.V15 (GND), U1.V25 (GND), U1.W2 (GND), U1.W12 (GND), U1.W22 (GND), U1.Y10 (GND), U1.Y11 (GND), U1.Y12 (GND), U1.Y13 (GND), U1.Y19 (GND), U2.4 (GND), U2.8 (SS), U2.EPAD, U3.4 (GND), U3.8 (SS), U3.EPAD, U5.1 (GROUND/ADJUST); also elsewhere on the board
unnamed: C21.2, R5.2
unnamed: C22.2, R6.2
unnamed: C17.1, U2.1 (BS)
unnamed: C21.1, U2.6 (COMP)
unnamed: R2.1, U2.7 (EN)
unnamed: R7.1, R9.1, U2.5 (FB)
unnamed: C17.2, L1.1, U2.3 (SW)
unnamed: C18.1, U3.1 (BS)
unnamed: C22.1, U3.6 (COMP)
unnamed: R1.1, U3.7 (EN)
unnamed: R8.1, R10.1, U3.5 (FB)
unnamed: C18.2, L2.1, U3.3 (SW)
unnamed: R3.2, R4.2, U4.1 (ADJ/GND)
VCCADC: C1.2, C2.2, C7.2, C8.2, C9.2, C10.2, C11.2, C13.2, C27.2, C29.2, C31.1, L2.2, R10.2, U1.J11 (VCCINT), U1.J13 (VCCINT), U1.K10 (VCCINT), U1.K12 (VCCINT), U1.L11 (VCCINT), U1.L13 (VCCINT), U1.M10 (VCCINT), U1.M12 (VCCADC_0), U1.N13 (VCCBRAM), U1.P10 (VCCINT), U1.R13 (VCCBRAM), U1.T10 (VCCINT), U1.T12 (VCCINT), U1.U11 (VCCINT), U1.U13 (VCCBRAM), U1.V10 (VCCINT), U1.V12 (VCCINT), U1.W13 (VCCBRAM)
VCCAUX: C12.2, C14.2, C15.2, C16.2, C20.2, C23.2, C25.1, C26.2, C28.2, C35.2, C36.2, C40.2, C41.2, C45.2, C46.2, C50.2, C51.2, C55.2, C56.2, C60.2, C61.2, C65.2, C66.2, U1.J9 (VCCAUX), U1.L9 (VCCAUX), U1.N9 (VCCAUX), U1.R9 (VCCAUX), U1.U9 (VCCAUX), U5.2 (VOUT); also elsewhere on the board
VCCOB0: C3.2, C4.2, C19.2, C30.1, C32.2, C33.2, C34.2, C37.2, C38.2, C39.2, C42.2, C43.2, C44.2, C47.2, C48.2, C49.2, C52.2, C53.2, C54.2, C57.2, C58.2, C59.2, C62.2, C63.2, C64.2, L1.2, R9.2, U4.3 (INPUT), U5.3 (VIN); also elsewhere on the board
VCCOB33: C24.2, C67.2, C68.2, C69.2, C70.2, C71.2, C72.2, C73.2, C74.2, C75.2, C76.2, C77.2, C78.2, C79.2, C80.2, C81.2, C82.2, C83.2, C84.2, C85.2, C86.2, C87.2, R4.1, U4.2 (OUTPUT); also elsewhere on the board

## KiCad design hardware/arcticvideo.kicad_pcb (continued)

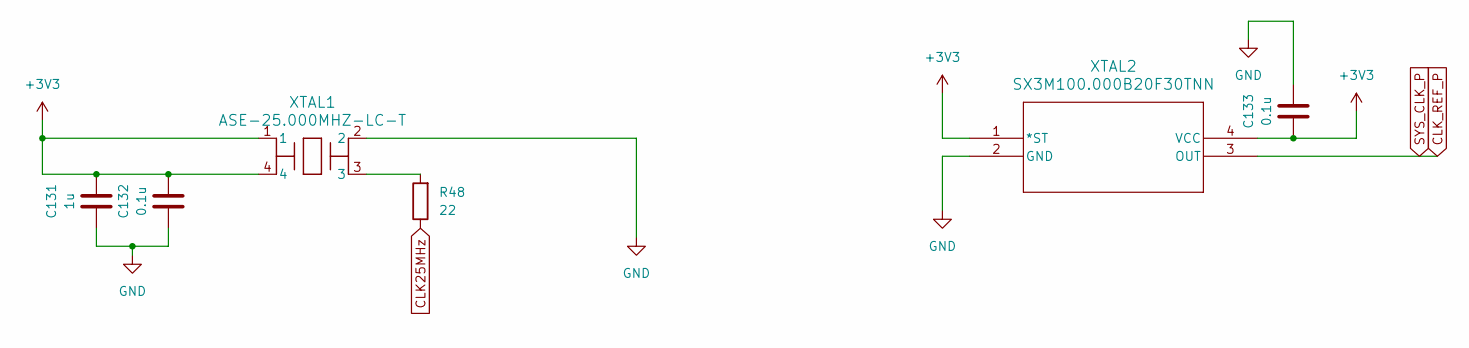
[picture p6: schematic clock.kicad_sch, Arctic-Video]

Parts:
C131: 1u; C_0402_1005Metric
C132, C133: 0.1u; C_0402_1005Metric
R48: 22; R_0402_1005Metric
XTAL1: ASE-25.000MHZ-LC-T; CHIP_ASE-24_ABR
XTAL2: SX3M100.000B20F30TNN; SG-210STF_EPS

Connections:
CLK25MHz: R48.1; also elsewhere on the board
CLK_REF_P: XTAL2.3 (OUT); also elsewhere on the board
GND: C131.1, C132.1, C133.2, XTAL1.2, XTAL2.2 (GND); also elsewhere on the board
unnamed: R48.2, XTAL1.3
VCCOB0: C131.2, C132.2, C133.1, XTAL1.1, XTAL1.4, XTAL2.1 (*ST), XTAL2.4 (VCC); also elsewhere on the board

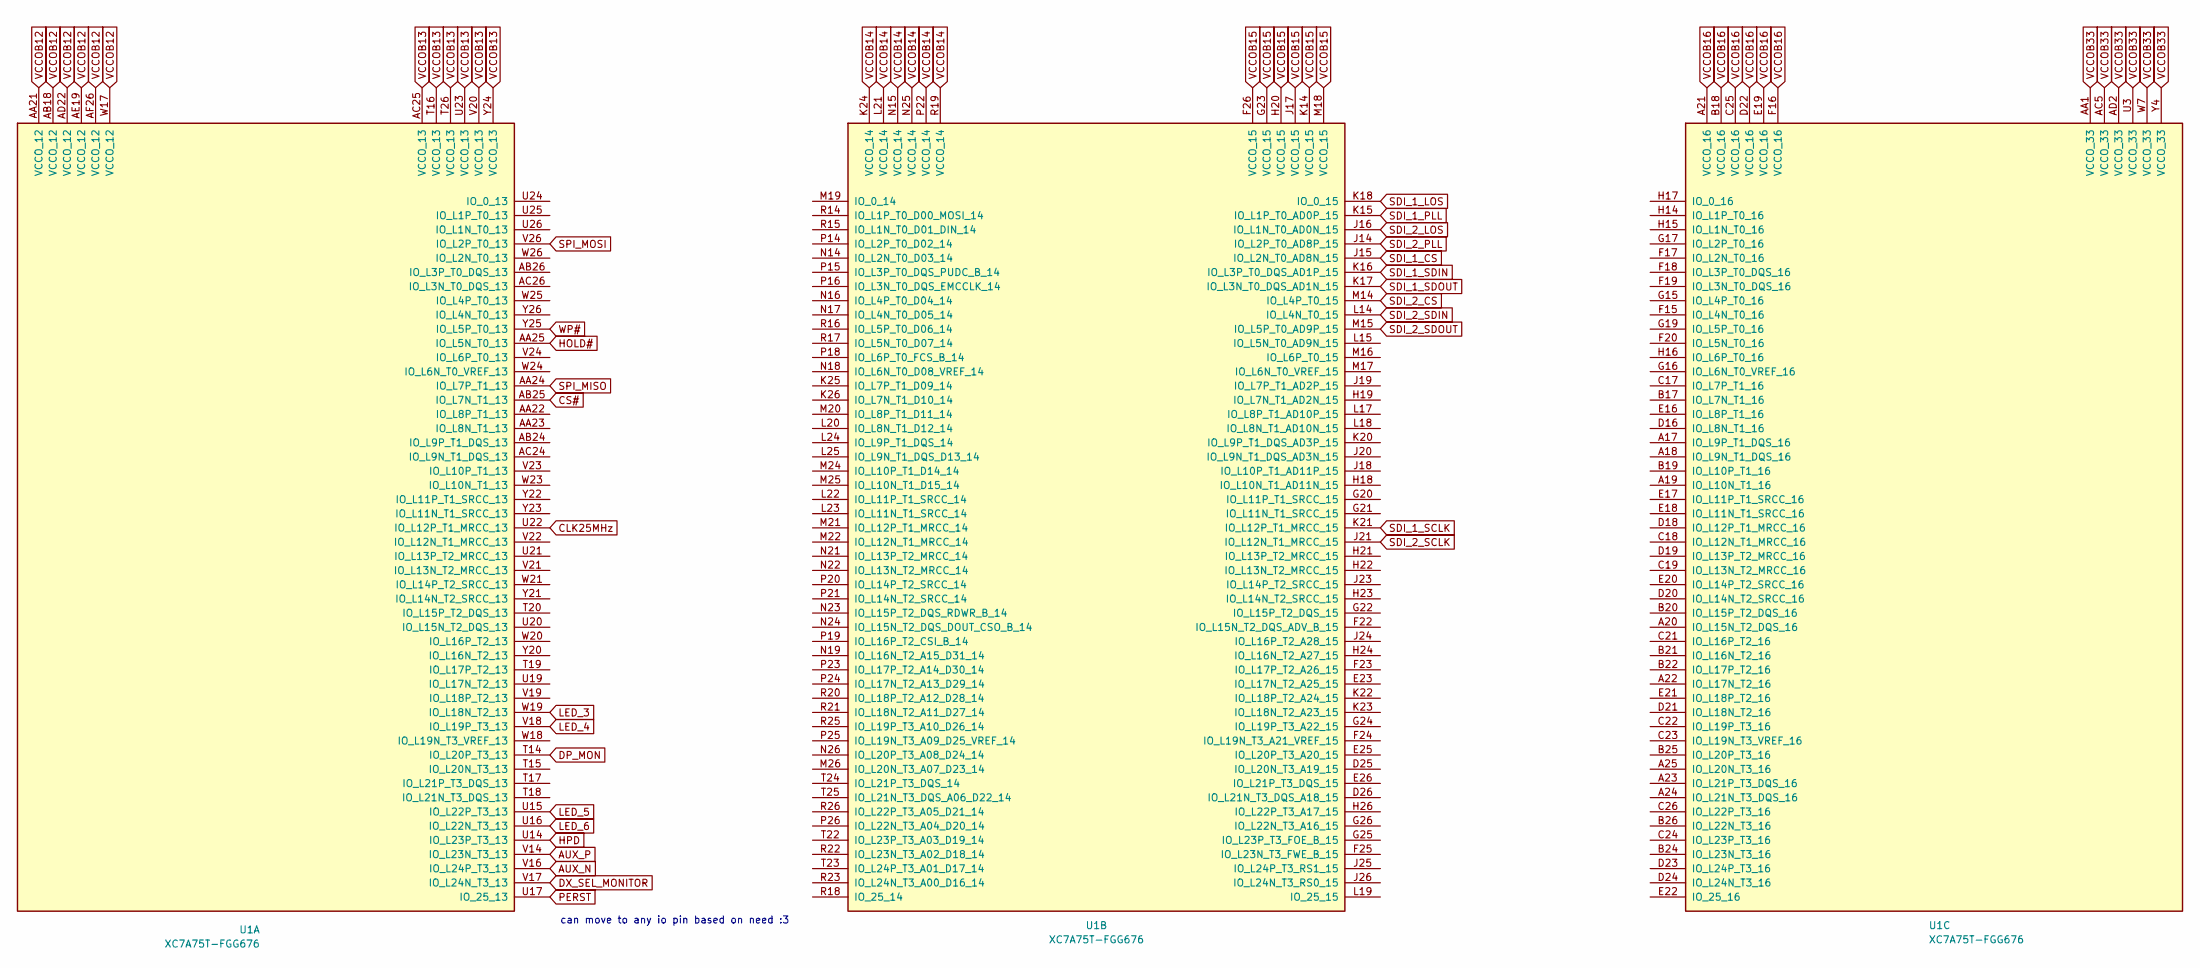
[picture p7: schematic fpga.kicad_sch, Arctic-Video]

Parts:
U1: XC7A75T-FGG676; Xilinx_FGG676

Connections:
AUX_N: U1.V16 (IO_L24P_T3_13); also elsewhere on the board
AUX_P: U1.V14 (IO_L23N_T3_13); also elsewhere on the board
CLK25MHz: U1.U22 (IO_L12P_T1_MRCC_13); also elsewhere on the board
CS#: U1.AB25 (IO_L7N_T1_13); also elsewhere on the board
DP_MON: U1.T14 (IO_L20P_T3_13); also elsewhere on the board
DX_SEL_MONITOR: U1.V17 (IO_L24N_T3_13); also elsewhere on the board
HOLD#: U1.AA25 (IO_L5N_T0_13); also elsewhere on the board
HPD: U1.U14 (IO_L23P_T3_13); also elsewhere on the board
LED_3: U1.W19 (IO_L18N_T2_13); also elsewhere on the board
LED_4: U1.V18 (IO_L19P_T3_13); also elsewhere on the board
LED_5: U1.U15 (IO_L22P_T3_13); also elsewhere on the board
LED_6: U1.U16 (IO_L22N_T3_13); also elsewhere on the board
PERST: U1.U17 (IO_25_13); also elsewhere on the board
SDI_1_CS: U1.J15 (IO_L2N_T0_AD8N_15); also elsewhere on the board
SDI_1_LOS: U1.K18 (IO_0_15); also elsewhere on the board
SDI_1_PLL: U1.K15 (IO_L1P_T0_AD0P_15); also elsewhere on the board
SDI_1_SCLK: U1.K21 (IO_L12P_T1_MRCC_15); also elsewhere on the board
SDI_1_SDIN: U1.K16 (IO_L3P_T0_DQS_AD1P_15); also elsewhere on the board
SDI_1_SDOUT: U1.K17 (IO_L3N_T0_DQS_AD1N_15); also elsewhere on the board
SDI_2_CS: U1.M14 (IO_L4P_T0_15); also elsewhere on the board
SDI_2_LOS: U1.J16 (IO_L1N_T0_AD0N_15); also elsewhere on the board
SDI_2_PLL: U1.J14 (IO_L2P_T0_AD8P_15); also elsewhere on the board
SDI_2_SCLK: U1.J21 (IO_L12N_T1_MRCC_15); also elsewhere on the board
SDI_2_SDIN: U1.L14 (IO_L4N_T0_15); also elsewhere on the board
SDI_2_SDOUT: U1.M15 (IO_L5P_T0_AD9P_15); also elsewhere on the board
SPI_MISO: U1.AA24 (IO_L7P_T1_13); also elsewhere on the board
SPI_MOSI: U1.V26 (IO_L2P_T0_13); also elsewhere on the board
VCCAUX: U1.A21 (VCCO_16), U1.B18 (VCCO_16), U1.C25 (VCCO_16), U1.D22 (VCCO_16), U1.E19 (VCCO_16), U1.F16 (VCCO_16), U1.F26 (VCCO_15), U1.G23 (VCCO_15), U1.H20 (VCCO_15), U1.J17 (VCCO_15), U1.K14 (VCCO_15), U1.M18 (VCCO_15); also elsewhere on the board
VCCOB0: U1.AA21 (VCCO_12), U1.AB18 (VCCO_12), U1.AC25 (VCCO_13), U1.AD22 (VCCO_12), U1.AE19 (VCCO_12), U1.AF26 (VCCO_12), U1.K24 (VCCO_14), U1.L21 (VCCO_14), U1.N15 (VCCO_14), U1.N25 (VCCO_14), U1.P22 (VCCO_14), U1.R19 (VCCO_14), U1.T16 (VCCO_13), U1.T26 (VCCO_13), U1.U23 (VCCO_13), U1.V20 (VCCO_13), U1.W17 (VCCO_12), U1.Y24 (VCCO_13); also elsewhere on the board
VCCOB33: U1.AA1 (VCCO_33), U1.AC5 (VCCO_33), U1.AD2 (VCCO_33), U1.U3 (VCCO_33), U1.W7 (VCCO_33), U1.Y4 (VCCO_33); also elsewhere on the board
WP#: U1.Y25 (IO_L5P_T0_13); also elsewhere on the board

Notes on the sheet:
can move to any io pin based on need :3

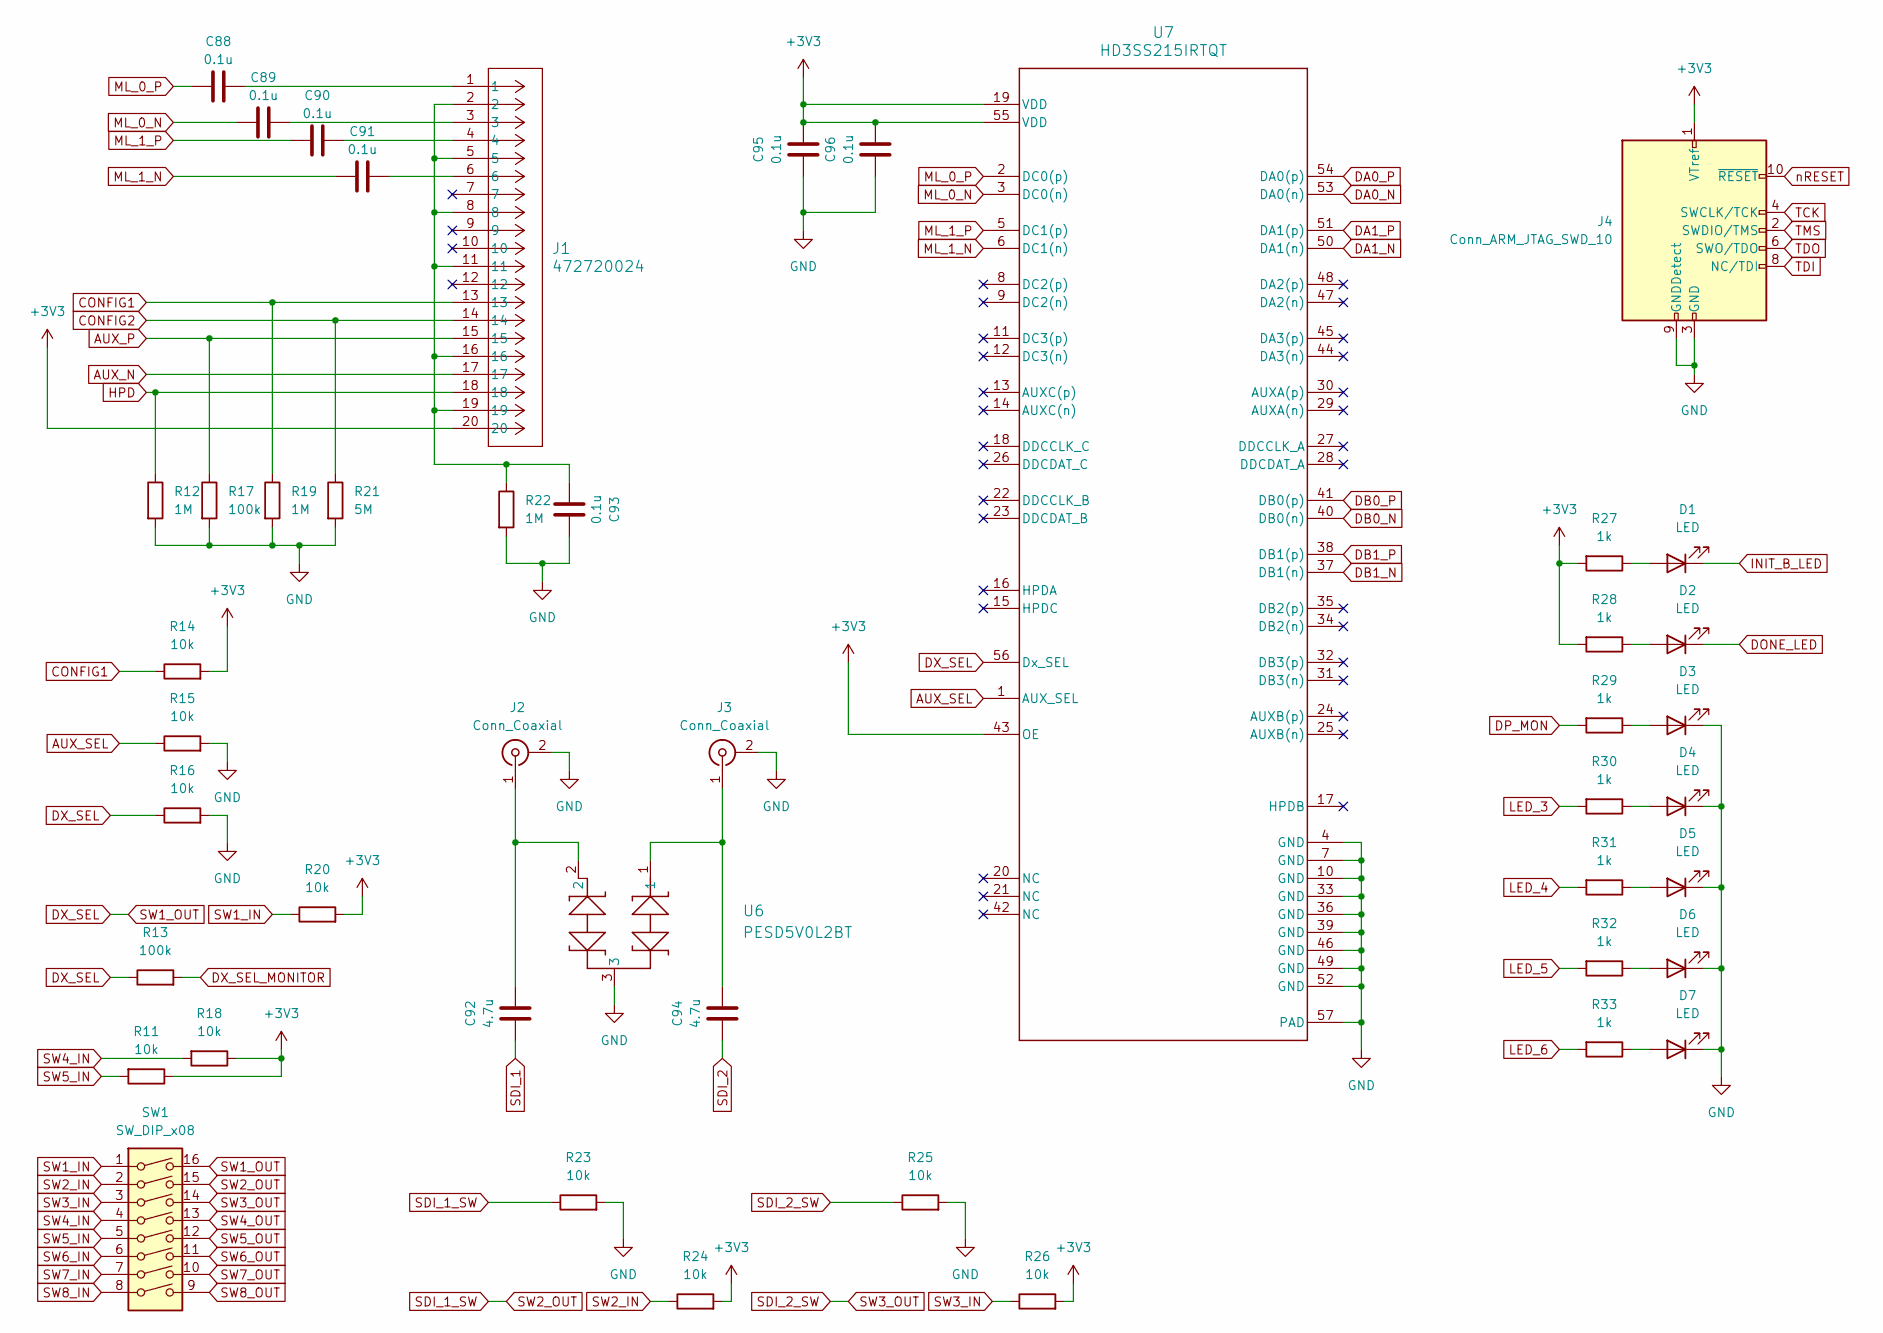
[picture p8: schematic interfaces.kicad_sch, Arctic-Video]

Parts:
C88, C89, C90, C91, C93, C95, C96: 0.1u; C_0402_1005Metric
C92, C94: 4.7u; C_0402_1005Metric
D1, D2, D3, D4, D5, D6, D7: LED; LED_0402_1005Metric
J1: 472720024; CONN_47272-0024_MOL
J2, J3: Conn_Coaxial; SAMTEC_BNC7T-J-P-XX-ST-EM1D
J4: Conn_ARM_JTAG_SWD_10; PinSocket_2x05_P2.54mm_Vertical
R11, R14, R15, R16, R18, R20, R23, R24, R25, R26: 10k; R_0402_1005Metric
R12, R19, R22: 1M; R_0402_1005Metric
R13, R17: 100k; R_0402_1005Metric
R21: 5M; R_0402_1005Metric
R27, R28, R29, R30, R31, R32, R33: 1k; R_0402_1005Metric
SW1: SW_DIP_x08; SW_DIP_SPSTx08_Slide_9.78x22.5mm_W7.62mm_P2.54mm
U6: PESD5V0L2BT; SOT23_NEX
U7: HD3SS215IRTQT; RTQ0056B

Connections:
AUX_N: J1.17; also elsewhere on the board
AUX_P: J1.15, R17.1; also elsewhere on the board
AUX_SEL: R15.1, U7.1 (AUX_SEL)
CONFIG1: J1.13, R14.1, R19.1
CONFIG2: J1.14, R21.1
DA0_N: U7.53 (DA0(n)); also elsewhere on the board
DA0_P: U7.54 (DA0(p)); also elsewhere on the board
DA1_N: U7.50 (DA1(n)); also elsewhere on the board
DA1_P: U7.51 (DA1(p)); also elsewhere on the board
DB0_N: U7.40 (DB0(n)); also elsewhere on the board
DB0_P: U7.41 (DB0(p)); also elsewhere on the board
DB1_N: U7.37 (DB1(n)); also elsewhere on the board
DB1_P: U7.38 (DB1(p)); also elsewhere on the board
DONE_LED: D2.1 (K); also elsewhere on the board
DP_MON: R29.2; also elsewhere on the board
DX_SEL: R13.1, R16.1, SW1.16, U7.56 (Dx_SEL)
DX_SEL_MONITOR: R13.2; also elsewhere on the board
GND: C93.2, C95.1, C96.1, D3.1 (K), D4.1 (K), D5.1 (K), D6.1 (K), D7.1 (K), J2.2 (Ext), J3.2 (Ext), J4.3 (GND), J4.5 (GND), J4.9 (GNDDetect), R12.2, R15.2, R16.2, R17.2, R19.2, R21.2, R22.2, R23.2, R25.2, U6.3, U7.4 (GND), U7.7 (GND), U7.10 (GND), U7.33 (GND), U7.36 (GND), U7.39 (GND), U7.46 (GND), U7.49 (GND), U7.52 (GND), U7.57 (PAD); also elsewhere on the board
HPD: J1.18, R12.1; also elsewhere on the board
INIT_B_LED: D1.1 (K); also elsewhere on the board
LED_3: R30.2; also elsewhere on the board
LED_4: R31.2; also elsewhere on the board
LED_5: R32.2; also elsewhere on the board
LED_6: R33.2; also elsewhere on the board
ML_0_N: C89.1, U7.3 (DC0(n))
ML_0_P: C88.1, U7.2 (DC0(p))
ML_1_N: C91.1, U7.6 (DC1(n))
ML_1_P: C90.1, U7.5 (DC1(p))
unnamed: C88.2, J1.1
unnamed: C89.2, J1.3
unnamed: C90.2, J1.4
unnamed: C91.2, J1.6
unnamed: C93.1, J1.2, J1.5, J1.8, J1.11, J1.16, J1.19, R22.1
unnamed: D1.2 (A), R27.1
unnamed: D2.2 (A), R28.1
unnamed: D3.2 (A), R29.1
unnamed: D4.2 (A), R30.1
unnamed: D5.2 (A), R31.1
unnamed: D6.2 (A), R32.1
unnamed: D7.2 (A), R33.1
unnamed: C92.2, J2.1 (In_1), U6.2
unnamed: C94.2, J3.1 (In_1), U6.1
SDI_1: C92.1; also elsewhere on the board
SDI_1_SW: R23.1, SW1.15
SDI_2: C94.1; also elsewhere on the board
SDI_2_SW: R25.1, SW1.14
SW1_IN: R20.1, SW1.1
SW2_IN: R24.1, SW1.2
SW3_IN: R26.1, SW1.3
SW4_IN: R18.2, SW1.4
SW4_OUT: SW1.13; also elsewhere on the board
SW5_IN: R11.2, SW1.5
SW5_OUT: SW1.12; also elsewhere on the board
SW6_IN: SW1.6
SW6_OUT: SW1.11
SW7_IN: SW1.7
SW7_OUT: SW1.10
SW8_IN: SW1.8
SW8_OUT: SW1.9
TCK: J4.4 (SWCLK/TCK); also elsewhere on the board
TDI: J4.8 (NC/TDI); also elsewhere on the board
TDO: J4.6 (SWO/TDO); also elsewhere on the board
TMS: J4.2 (SWDIO/TMS); also elsewhere on the board
VCCOB0: C95.2, C96.2, J1.20, J4.1 (VTref), R11.1, R14.2, R18.1, R20.2, R24.2, R26.2, R27.2, R28.2, U7.19 (VDD), U7.43 (OE), U7.55 (VDD); also elsewhere on the board
nRESET: J4.10 (~RESET); also elsewhere on the board

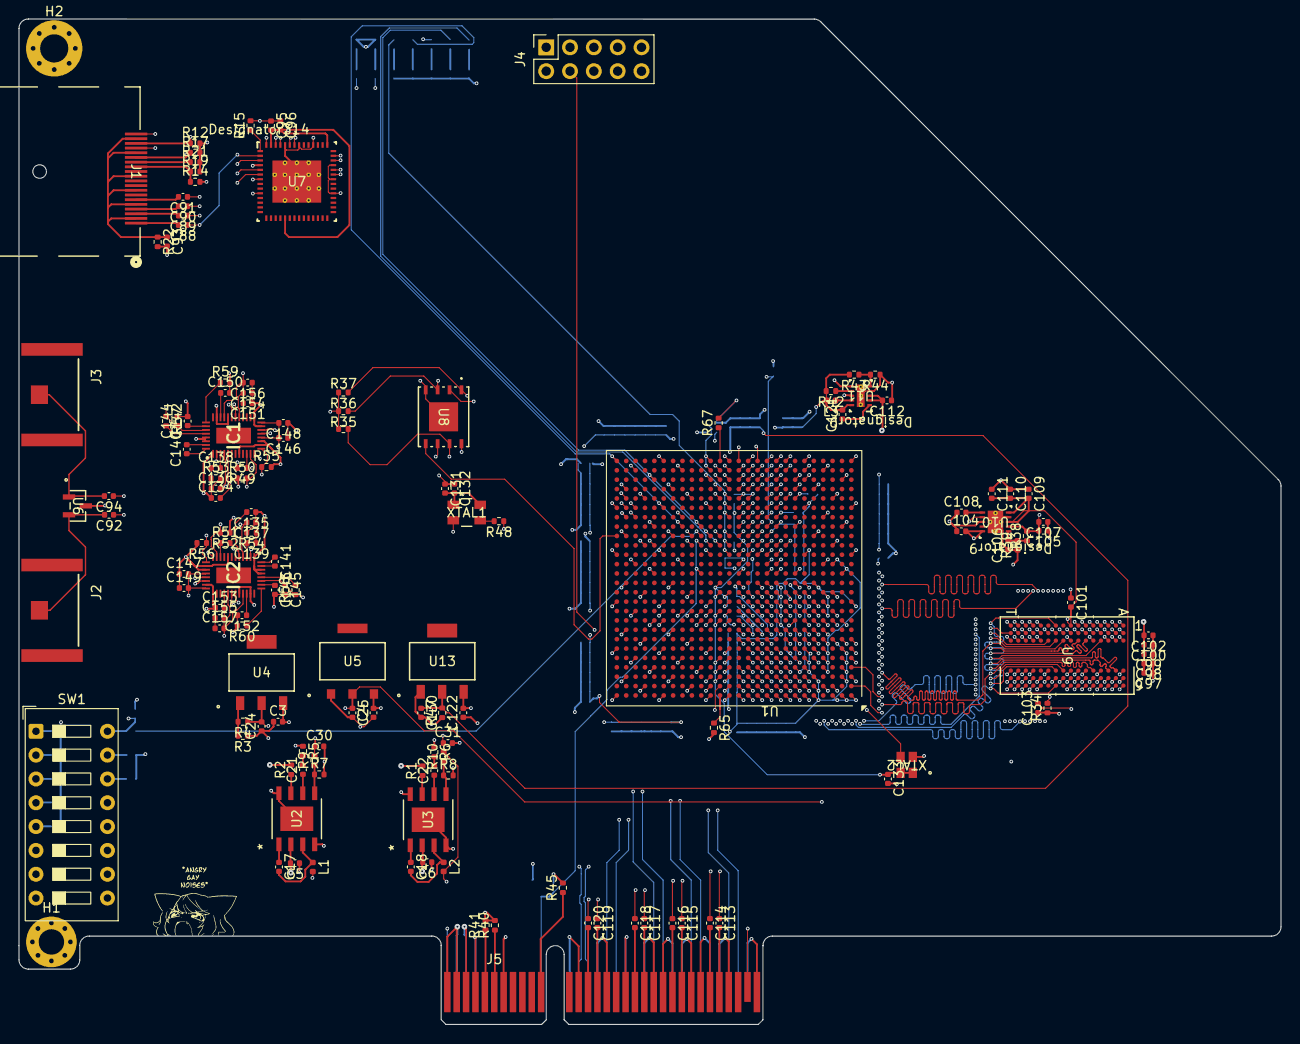
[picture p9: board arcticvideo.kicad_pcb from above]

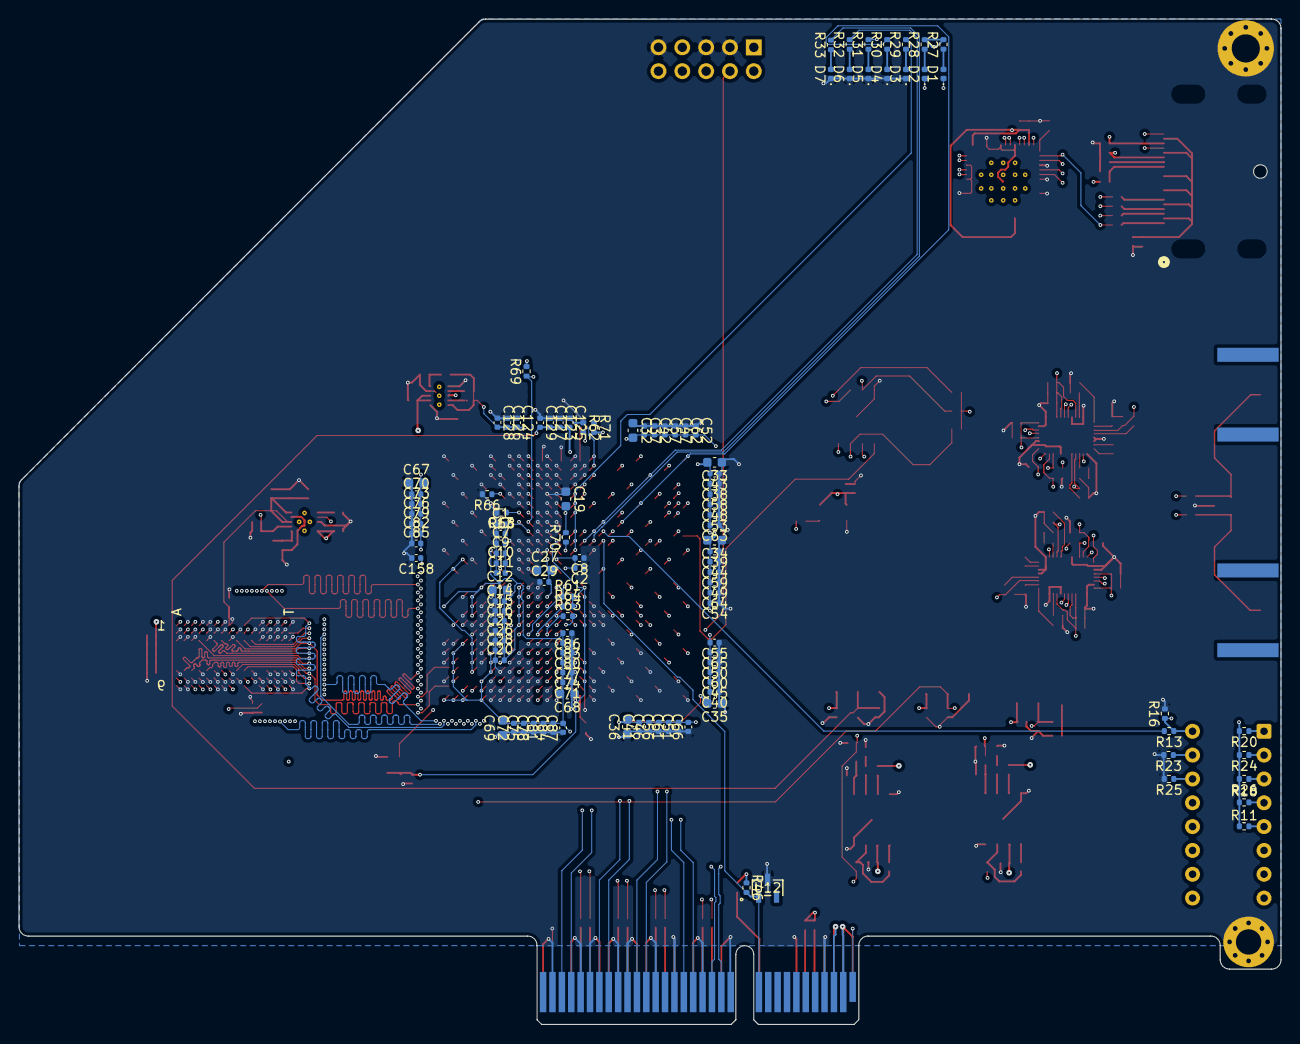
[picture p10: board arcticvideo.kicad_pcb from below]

Board: 8 copper layers, 134.5 x 107.2 mm, 264 parts (117 on the bottom side), 213 nets.

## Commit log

2026-06-19 finished pcie interface
    [arcticvideo.kicad_pcb, arcticvideo.kicad_sch, clock.kicad_sch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]
2026-06-21 last commit for a while, i have to change the fpga and i dont have the time, money, or motivation to do that
    [arcticvideo.kicad_sch, clock.kicad_sch, flashram.kicad_sch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]
2026-06-23 finished schematic!!! :D (before peer review)
    [flashram.kicad_sch, fpga.kicad_sch, fpga1.kicad_sch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]
2026-06-24 small changes
    [fpga.kicad_sch]
2026-06-24 readable changes
    [clock.kicad_sch, flashram.kicad_sch, fpga1.kicad_sch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]
2026-06-26 pcb routing
    [arcticvideo.kicad_pcb, clock.kicad_sch, flashram.kicad_sch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]
2026-06-26 pcb changes v2
    [arcticvideo.kicad_pcb]
2026-07-03 pcb things
    [arcticvideo.kicad_pcb, flashram.kicad_sch, interfaces.kicad_sch]
2026-07-10 finished pcb
    [arcticvideo.kicad_pcb, bom.csv, clock.kicad_sch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]
2026-07-10 added changed
    [arctic-video-bracket.stl, arctic-video.blend, arcticvideo.kicad_pcb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]
